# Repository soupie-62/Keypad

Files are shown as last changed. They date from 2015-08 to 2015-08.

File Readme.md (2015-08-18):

Version 2C:
----------
100mm x 60mm<p>
Small enough for cheaper PCB costs<p>
Problems:<p>
	Mounting holes too close too switches<p>

[made pcb]

Version 2B:<p>
----------<p>
49 keys, 120 mm x 55 mm board<p>
Improved button spacing, better mounting hole placement<p>
Problem: Itead Studio want boards <10 cm (100mm)<p>
	Need to move mounting holes, and squeeze buttons together a bit…<p>
<p>
Version 2A:<p>
----------<p>
44 keys, 10cm x 5cm board<p>
Improved button spacing, better mounting hole placement<p>
<p>
<p>
Version 1:<p>
----------<p>
49 keys, 10cm x 5cm board

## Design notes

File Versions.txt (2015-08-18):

Version 2C:
----------
There are now 2 distinct layouts.
#1:	49 Keys, 100mm x 50mm board.
	10 x 5 buttons, with one "double-width" button on bottom row.
	This board, when combined with a large LCD, would be in a typical
	"clamshell" layout, similar to a laptop.

#2:	47 Keys, 100mm x 60mm board.
	2 rows, 4 buttons wide [8 total].
	4 rows, 10 buttons wide, with one "double-width" button on bottom row [39 total].
	This board has a "cutout" area, allowing a smaller LCD to be added to the top.
	"Landscape" layout, similar to a HP 15C

Version #2 is also being developed as an Android app, using the Nexus 7. 

Version 2B:
----------
49 keys, 120 mm x 55 mm board
Improved button spacing, better mounting hole placement

Problem:	Itead Studio want boards <10 cm (100mm)

		Need to move mounting holes, and squeeze buttons together a bit…

Version 2A:
----------
44 keys, 10cm x 5cm board
Improved button spacing, better mounting hole placement

Version 1:
----------
49 keys, 10cm x 5cm board

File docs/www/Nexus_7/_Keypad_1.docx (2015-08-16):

Keypad – some calculations

This keypad needs to be both physical, and virtual (emulated on a tablet). When physical, a “clamshell” design would allow a large keypad, with a large screen that folds over the top when the device is closed.

The emulated version would not be able to do that.

If the keypad and screen form a single unit, dimensions come into play. A screen the same size as the keypad makes the whole device too big. A screen the same width as the keypad, but shorter, might be the right size – but there’s not enough room on the screen.

The next option is: have a narrower (but taller) screen, with keys underneath and to one side. This also allows the screen to show custom labels, for the row of keys immediately below the screen.

The overall height of the screen, and the size of the text, now need to be determined. A failure to fix these risks feature “redesign” slowing overall project progress.

Tablet Dimensions 1: Ipad

The Ipad screen is 1024 x 768. Assuming 100 pixels wide by 96 high, we can fit up to 7 rows on the screen, leaving 96 pixels. By limiting to 4 rows under the “display” section, we get a display height of 384 pixels.

If the display is equal to the width of six keys, that is a total display area of 600 x 384. By using a font width of 30 pixels, 20 characters per line is possible (The old HP 41C supported 16 chars).

For key labels, assuming labels are no more than 6 chars long, the font needs to be about 15 pixels wide (36 chars total). Assuming three rows of key labels, each row 21 pixels high, the label area is 63 pixels.

With a display of 600 x 321 (384 – 63), and a font 42 pixels high, about seven lines of text / numbers can be displayed.

By reducing the height of each key row to 72 pixels, OR reducing to 3 rows of keys, the display increases to 600 x 417 (480 – 63, about 9 lines). Combining these options gives a display of 600 x 489 (552 – 63, 11 lines).

Dot Matrix (extrapolated)

Width | 5 | 10 | 15 | 30 | 50
Height | 7 | 14 | 21 | 42 | 70

Tablet Dimensions 1: Nexus 7 (2013 Edition)

The (2013) Nexus 7 screen is 1920W x 1200H. Assuming buttons are 190W x 160H, we can fit 7 rows on the screen, leaving 80 pixels free. Limit to 4 rows under the “display”, get a display height of (80 + 160 + 160 + 160) 560 pixels.

If the display is six keys wide, the total display area is: 1140W x 560H. Using a font 50 pixels wide, 22 characters per line is possible.

For key labels, assuming labels are no more than 6 chars long, the font needs to be about 30 pixels wide (36 chars total). Assuming three rows of key labels (plain, F and G), each row 40 pixels high, the label area is 120H.

With a display of 1140W x 440H (560 – 120), and a font 70 pixels high, about six lines of text / numbers can be displayed.

The physical dimensions of the Nexus 7 are: 114mm W x 200mm H x 8.65mm D
The screen is: 94mm W x 151 mm D

Each button is 190W. Most buttons have 2 labels above (alpha and green menu) , or 2 labels below (F and G functions). Using a font 20W allows 9 characters per label.

Keycap Size, Spacing and Alignment

Almost all regular PC keyboards use keycaps of the approximate same size. In this context, I am referring to "size" as the width and depth of each keycap (the height of the keycaps we'll examine when we talk about travel (http://www.pcguide.com/ref/kb/const/cap_Travel.htm).) The size of a regular keycap is approximately 0.5 inches (12.7mm) square on the top of the keycap. The keycap then tapers down to a larger size at its base; a little under 0.75 inches (19mm) square (about 11/16ths of an inch).

Spacing of keycaps is also very standardized, at about 0.75 inches from the center of one key to the center of its neighbor on either side. Each row of keys in the main alphanumeric area of the keyboard is also separated by about 0.75 inches of space in a typical keyboard.

The next issue is the alignment of the rows of keys in the main part of the keyboard. By this I mean how the keys in one row are offset, left to right, relative to the keys in the row above and below it. Here too there is a standard configuration which is rarely violated. Let's call the bottom row of alphanumeric keys (containing "Z" and "X") row #1. Then the "home row" containing "A" and "S" would be row #2, the row with "Q" and "W" row #3, and the row with the numeric symbols row #4. Alignment is as follows:

- Row #1 is offset from row #2 by about one-half of a key-spacing. That's 3/8ths (0.375) inches (9.525mm).
- Row #2 is offset from row #3 by about one-quarter of a key-spacing, or 3/16ths (0.188) inches (4.7625mm). This one's the oddball; I don't know why it isn't 3/8ths like the others, but it isn't. :^)
- Row #3 is offset from row #4 by 3/8ths inches like the offset of row #1 and row #2.

Again, we are discussing the regular alphanumeric keys here; the size, spacing and location of the keys other than the main alphanumerics varies greatly from one keyboard to another. These are discussed in the description of keyboard layouts (http://www.pcguide.com/ref/kb/layout/index.htm). Also, special keys such as the <Enter> key and <Space Bar> are often of different sizes and spacing can be very different between models.

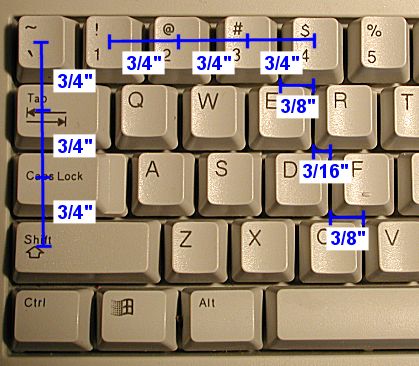
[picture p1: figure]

Illustration of a typical keyboard showing the spacing between
keys and rows of keys, as well as the offsets between adjacent
rows of keys in the main typing area of the keyboard.

The reason for standardized keycap size, spacing and alignment is a simple one: not having a standard would make everyone who has to use more than one keyboard utterly miserable. Touch typists and data entry people learn the "feel" of a keyboard and become used to its spacing and the size of its keys. Moving between two keyboards with different-sized keys or keys with different spacings would slow people down. It would also cause major retraining problems for new employees, or if you bought a new PC, and so on.

There is one place where non-standard keycap size and spacing may sometimes be seen: in very small notebook PCs or PC-like devices. This would be due to the need to conserve space. Fortunately, most notebooks do come with keycaps of standard size and spacing, especially now that if anything, notebooks are getting wider due to the desire for larger screens. However, there is also a growing market for very small "sub-notebooks", and here, "shrunken" keycaps are sometimes found. The exact layout of keys is sometimes a bit strange with notebooks (http://www.pcguide.com/ref/kb/layout/non_Note.htm) but at least usually the regular keys are where they should be--without that, anyone working on both a desktop and notebook machine would find life a bit difficult in this regard.

Keycap Travel

A very important ergonomic and comfort design factor for keyboards is keycap travel. This refers to the distance the keycaps move when the keys are pressed. A keyboard whose keys move down a great deal (relatively speaking) is said to have a "long" travel, while one whose keys move relatively little has a "short" travel. Travel is determined in part by overall keyboard design, but is also a function of the keyswitch technology (http://www.pcguide.com/ref/kb/const/switch.htm) used.

Travel is an important consideration for touch typists and others who use their keyboards a great deal. Good keyboards, all else being equal, usually have a fairly long travel, about 0.15 inches or more. Less expensive keyboards, or keyboards used in applications where saving space is important, often have travel of less than 0.10 inches (2.54mm). The difference may seem insignificant, but it definitely is not. My regular PC keyboard has a travel of about 0.16 inches (4.06mm); my notebook keyboard is about 0.12 inches (3.05mm). I can use both, but the full-sized keyboard is much more comfortable on my fingers.

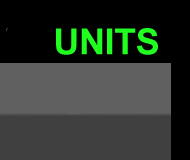
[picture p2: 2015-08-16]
docs/www/Nexus_7/H/H_R2C9.png

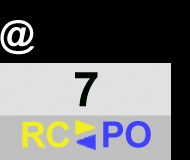
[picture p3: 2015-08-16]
docs/www/Nexus_7/alpha/A_R2C1.png

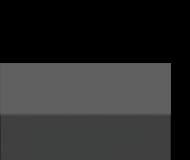
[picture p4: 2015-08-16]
docs/www/Nexus_7/H/H_R1C0.png

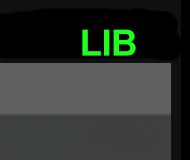
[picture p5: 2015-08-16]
docs/www/Nexus_7/H/H_R4C6.png

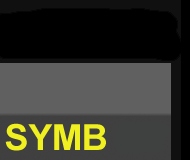
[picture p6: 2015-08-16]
docs/www/Nexus_7/F/F_R5C5.png

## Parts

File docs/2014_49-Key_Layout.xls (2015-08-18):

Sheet: Pad
A | Solve | B | Lib | C | Fin | D | Prob | E | Plot | F | Symb | G |  | I / O | ( | |x| |  | ) | Stk | CLΣ
F1 |  | F2 |  | F3 |  | F4 |  | F5 |  | F6 |  | 1/x |  |  | √x |  |  | ▲ |  | CLR
 |  |  |  |  |  |  |  |  |  |  |  | y^x |  |  | x^2 |  |  | Drop |  | Del
H | Stat | I | Time | J | Units | K | Logic | L | Flags | M | Const | ≈ |  | Mode | < | << |  | # | R↑ | > | >>
× |  | 7 |  | 8 |  | 9 |  | +/- |  | Log |  | Ln |  |  | ◄ |  |  | ▼ |  | ►
ST× |  | RC PO |  | i Ð |  | Δ% |  | X.Fcn |  | 10^x |  | e^x |  |  | [ ] |  |  | R↓ |  | Swap
N |  | O |  | P |  | Q |  | R |  | S | 2d | " |  | π | $ | ∂ |  | ; | ∫ | @ | Σ
÷ |  | 4 |  | 5 |  | 6 |  | EXP |  | x⇄y |  | Hyp |  |  | SIN |  |  | COS |  | TAN
ST÷ :: |  | b/c .d |  | P Cy,x |  | DRG◄ |  | Lin Rg |  | x⇄ |  | " " |  |  | asin |  |  | acos |  | atan
T |  | U |  | V |  | W |  | X |  | Y | 2^x | ! |  | !( ) | & | && |  | | | || | ^ | ^^
+ |  | 1 |  | 2 |  | 3 |  | SST |  | STO |  | RCL |  |  |  |  |  | GTO |  | XEQ
ST+ Σ+ |  | Eval |  | Mod |  | Cat |  | BST |  | ~ not |  | x! |  |  | & and |  |  | | or |  | ^ xor
Z |  | % |  | Space |  |  | RTN | Eqn |  | Eqn Lib |  |  | Prgm |  |  |  | H |  |  |  | Off
- |  | 0 |  | . |  | R / S |  | ENTER |  |  |  | α |  |  | F |  |  | G |  | ON
ST- Σ- |  | H.ms |  | , = |  | LBL |  | Matrix |  |  |  | User |  |  |  |  |  |  |  | Off

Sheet: Thoughts
A |  | Solve |  |  | B |  | Plot |  | C | Symb | D |  | Time | E | Stat | F | Units | G |  | H |  |  |  | ≈ | Stk |  | CLΣ
 |  |  |  |  |  |  |  |  |  |  |  |  |  |  |  |  |  | 1/x |  | √x |  |  |  | ▲ |  |  | CLR
 |  |  |  |  |  |  |  |  |  |  |  |  |  |  |  |  |  | y^x |  | x^2 |x| |  |  |  | Drop |  |  | Del
I |  | Prob |  |  | J |  | Lib |  | K | Eq Lb | L |  | Fin | M | I / O | N | Flags | O |  | < | << |  |  | # |  |  | > | >>
× |  |  |  |  | 7 |  |  |  | 8 |  | 9 |  |  | +/- |  | LOG |  | Ln |  | ◄ |  |  |  | ▼ |  |  | ►
i Ð |  |  |  |  | RC PO |  |  |  | H.ms |  | Δ% |  |  | X.Fcn |  | 10^x |  | e^ 2^x |  | [ ] |  |  |  | R↓ ↑ |  |  | Swap
P |  | Logic |  |  | Q |  | Const |  | R |  | S |  |  | T |  | U |  | V |  | " |  |  |  | ; |  |  | @
÷ |  |  |  |  | 4 |  |  |  | 5 |  | 6 |  |  | EXP |  | x⇄y |  | Hyp |  | SIN |  |  |  | COS |  |  | TAN
Fix :: |  |  |  |  | b/c .d |  |  |  | P Cy,x |  | DRG◄ |  |  | Lin R |  | " " 2d |  | Eqn π |  | asin ∂ |  |  |  | acos ∫ |  |  | atan Σ
W |  |  |  |  | X |  |  |  | Y |  | Z |  |  |  |  | ! |  | & |  | % |  |  |  | ^ |  |  | $ | Cat
+ |  |  |  |  | 1 |  |  |  | 2 |  | 3 |  |  | E N T E R |  | STO |  | RCL |  | Mode |  |  |  | Menu |  |  | XEQ
Sci Σ+ |  |  |  |  |  |  |  |  |  |  |  |  |  |  |  | x! !( ) |  | Eval && |  | Mod || |  |  |  | xor |  |  | GTO
( |  |  |  |  | ) |  |  |  | Space |  |  |  | RTN |  |  | : |  |  | Prgm |  |  | H |  |  |  |  |  | Off
- |  |  |  |  | 0 |  |  |  | . |  | R / S |  |  |  |  | SST |  | α |  | G |  |  |  | F |  |  | ON
Eng Σ- |  |  |  |  |  |  |  |  | , = |  | LBL |  |  | Matrix |  | BST |  | User |  |  |  |  |  |  |  |  | Off
 | Mode: |  |  | 12h |  | 12 Hour Clock |  |  |  |  |  | 10 x 5 = 50 keys (ENTER = 2 spaces) -> 49 Keys |  |  |  |  |  |  |  | ARM Flags: |  | Z | Zero |  |  | C | Carry
 |  |  |  | 1C |  | Integer, 1's Complement |  |  |  |  |  |  |  |  |  |  |  |  |  |  |  | N | Negative |  |  | V | Overflow
 |  |  |  | 24h |  | 24 Hour Clock
 |  |  |  | 2C |  | Integer, 2's Complement
 |  |  |  | Base n |  | Integer, Base (2 to 16)
 |  |  |  | BestF |  | "Best Fit" curve model
 |  |  |  | CAS |  | Computer Algebra System (Symbolic math)
 |  |  |  | CPX |  | Complex math
 |  |  |  | DBL |  | "Double" Precision
 |  |  |  | FAST |  | Faster CPU, uses more battery power (Default)
 |  |  |  | SLOW |  | Slower CPU, saves battery
 |  |  | ANGLE: |  |  |  |  | Symbol font, code 208

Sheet: Pad_1
A |  |  |  | B |  |  | C | D |  |  | E |  | F | G |  |  | H |  |  |  | ^ | Stk |  |  | CLΣ
 |  |  |  |  |  |  |  |  |  |  |  |  |  | 1/x |  |  | √x |  |  |  | ▲ |  |  |  | CLR
Solve |  |  |  | Plot |  |  | Symb | Time |  |  | Stat |  | Units | y^x |  |  | x^2 |x| |  |  |  | Drop |  |  |  | Del
I |  |  |  | J |  |  | K | L |  |  | M | Rem | N | O |  |  | < |  |  |  | & |  |  |  | > |  | Cat
× |  |  |  | 7 |  |  | 8 | 9 |  |  | +/- |  | LOG | Ln |  |  | ◄ |  |  |  | ▼ |  |  |  | ►
i Ð |  |  |  | RC PO |  |  | H.ms | Δ% |  |  | Mod |  | 10^x | e^ 2^x |  |  | [ ] I/O |  |  |  | R↓ ↑ |  |  |  | Swap
P |  |  |  | Q |  |  | R | S |  |  | T | L.R | U | V |  |  | " |  |  |  | ; |  |  |  | @
÷ |  |  |  | 4 |  |  | 5 | 6 |  |  | EXP |  | x⇄y | Hyp |  |  | SIN |  |  |  | COS |  |  |  | TAN
Fix :: |  |  |  | b/c .d |  |  | P Cy,x | DRG◄ |  |  | Print |  | " " 2d | Eqn π |  |  | asin ∂ |  |  |  | acos ∫ |  |  |  | atan Σ
W |  |  |  | X |  |  | Y | Z |  |  |  |  | # | ! |  |  | % |  |  |  | ≈ |  |  |  | $
+ |  |  |  | 1 |  |  | 2 | 3 |  |  | E N T E R |  | STO | RCL |  |  | Mode |  |  |  | Menu |  |  |  | XEQ
Sci Σ+ |  |  |  | Prob |  |  | Lib | Eq Lib |  |  |  |  | Eval | { } x! |  |  | X.Fcn |  |  |  | Flags |  |  |  | GTO
( |  |  |  | ) |  |  | Space |  |  | RTN |  |  | : |  | Prgm |  |  |  |  |  |  |  |  |  |  |  | Off
- |  |  |  | 0 |  |  | . | R / S |  |  |  |  | SST | α |  |  | G |  |  |  | F |  |  |  | ON
Eng Σ- |  |  |  | Fin |  |  | , = | LBL |  |  | Matrix |  | BST | User |  |  |  |  |  |  |  |  |  |  | Off
 | Mode: |  | 12h |  | 12 Hour Clock |  |  |  | 10 x 5 = 50 keys (ENTER = 2 spaces) -> 49 Keys |  |  |  |  |  |  |  | ARM Flags: |  | Z | Zero |  |  |  | C | Carry
 |  |  | 1C |  | Integer, 1's Complement |  |  |  |  |  |  |  |  |  |  |  |  |  | N | Negative |  |  |  | V | Overflow
 |  |  | 24h |  | 24 Hour Clock
 |  |  | 2C |  | Integer, 2's Complement |  |  |  |  |  |  |  |  |  |  | ARM Tests:
 |  |  | Base n |  | Integer, Base (2 to 16) |  |  |  |  |  |  |  |  |  |  | EQ |  | Equal, Z = 1 |  |  |  |  | NE |  | Not Equal, Z = 0
 |  |  | BestF |  | "Best Fit" curve model |  |  |  |  |  |  |  |  |  |  | CS |  | Carry Set, C = 1 |  |  |  |  | CC |  | Carry Clear, C = 0
 |  |  | CAS |  | Computer Algebra System (Symbolic math) |  |  |  |  |  |  |  |  |  |  | HS |  | U / S Higher or Same, C = 1 |  |  |  |  | LO |  | U / S Lower, C = 0
 |  |  | CPX |  | Complex math |  |  |  |  |  |  |  |  |  |  | MI |  | Minus, N = 1 |  |  |  |  | PL |  | Plus, N = 0
 |  |  | DBL |  | "Double" Precision |  |  |  |  |  |  |  |  |  |  | VS |  | Overflow, V = 1 |  |  |  |  | VC |  | No Overflow, V = 0
 |  |  | FAST |  | Faster CPU, uses more battery power (Default) |  |  |  |  |  |  |  |  |  |  | HI |  | U / S Higher, C = 1 , Z = 0 |  |  |  |  | LS |  | U / S Lower or same,
 |  |  | SLOW |  | Slower CPU, saves battery |  |  |  |  |  |  |  |  |  |  |  |  |  |  |  |  |  |  |  |  | C = 0, Z = 1
 |  | ANGLE: |  |  |  | Symbol font, code 208

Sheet: Pad_2
A | B | C | D |  | E |  | F | G |  | H | ^ | Stk | CLΣ
 |  |  |  |  |  |  |  | 1/x |  | √x | ▲ |  | CLR
Solve | Plot | Symb | Time |  | Stat |  | Units | y^x |  | x^2 |x| | Drop |  | Del
I | J | K | L |  | M | Rem | N | O |  | < | & |  | > | Cat
× | 7 | 8 | 9 |  | +/- |  | LOG | Ln |  | ◄ | ▼ |  | ►
i Ð | RC PO | H.ms | Δ% |  | Mod |  | 10^x | e^ 2^x |  | [ ] I/O | R↓ ↑ |  | Swap
P | Q | R | S |  | T | L.R | U | V |  | " | ; |  | @
÷ | 4 | 5 | 6 |  | EXP |  | x⇄y | Hyp |  | SIN | COS |  | TAN
Fix :: | b/c .d | P Cy,x | DRG◄ |  | Print |  | " " 2d | Eqn π |  | asin ∂ | acos ∫ |  | atan Σ
W | X | Y | Z |  |  |  | # | ! |  | % | ≈ |  | $
+ | 1 | 2 | 3 |  | E N T E R |  | STO | RCL |  | Mode | Menu |  | XEQ
Sci Σ+ | Prob | Lib | Eq Lib |  |  |  | Eval | { } x! |  | X.Fcn | Flags |  | GTO
( | ) | Space |  | RTN |  |  | : |  | Prgm |  |  |  |  | Off
- | 0 | . | R / S |  |  |  | SST | α |  | G | F |  | ON
Eng Σ- | Fin | , = | LBL |  | Matrix |  | BST | User |  |  |  |  | Off

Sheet: Menus
Menu |  | Straight | F | H | Menu |  | Straight | F | H | Menu |  | Straight | F | H | Menu |  | Straight |  | F
SOLVE | A |  |  |  | Plot | A | Zoom |  |  | Symb | A |  |  |  | Test | A | == | Equal, Z = 1 | != | Not Equal, Z = 0
 | B |  |  |  |  | B | (x,y) |  |  |  | B |  |  |  |  | B | CS | Carry Set, C = 1 | CC | Carry Clear, C = 0
 | C |  |  |  |  | C | Trace |  |  |  | C |  |  |  |  | C | >= | U / S Higher or Same, C = 1 | < | U / S Lower, C = 0
 | D |  |  |  |  | D | FCN |  |  |  | D |  |  |  |  | D | < 0 | Minus, N = 1 | > 0 | Plus, N = 0
 | E |  |  |  |  | E | Edit |  |  |  | E |  |  |  |  | E | VS | Overflow, V = 1 | VC | No Overflow, V = 0
 | F |  |  |  |  | F | Cancl |  |  |  | F |  |  |  |  | F | > | U / S Higher, C = 1 , Z = 0 | <= | U / S Lower or same, C = 0, Z = 1
Time | A | H.ms | H.d |  | Stat | A |  |  |  | Units | A | Length | Heat
 | B | H.ms+ | H.ms- |  |  | B | x hat |  |  |  | B | Mass | Time
 | C | 12h | 24h |  |  | C | y |  |  |  | C | Volume | Electr
 | D | Ticks |  |  |  | D | r |  |  |  | D | Area | Speed
 | E |  |  |  |  | E | s |  |  |  | E | Freq
 | F |  |  |  |  | F |  |  |  |  | F | Metric | Imperial
Prob | A | Pois |  |  | Lib | A |  |  |  | Eqn Lib | A
 | B | Binom |  |  |  | B |  |  |  |  | B
 | C |  |  |  |  | C |  |  |  |  | C
 | D |  |  |  |  | D |  |  |  |  | D
 | E |  |  |  |  | E |  |  |  |  | E
 | F | P y,x | C y, x |  |  | F |  |  |  |  | F
Mode | A | Int | Real | Double | Menu | A |  |  |  | Flags | A | SF | FS? | VS
 | B | Complex |  | BCD |  | B |  |  |  |  | B | CF | FC? | VC
 | C | DRG► | ◄DRG |  |  | C |  |  |  |  | C | FS?C | FS?S | FS?T
 | D | B2 | B8 | Bn |  | D |  |  |  |  | D | FC?C | FC?S | FC?T
 | E | B10 | B16 |  |  | E |  |  |  |  | E | ISG | ISE
 | F | 1's Comp | 2's Comp |  |  | F |  |  |  |  | F | DSL | DSE | DSZ
Const | A |  |  |  | Logic | A | And | Nand | Xor | TRIG | A | sinh | asinh | D-R
 | B |  |  |  |  | B | Or | Nor | Xnor |  | B | cosh | acosh | D-G
 | C |  |  |  |  | C | Not | TEST | CS |  | C | tanh | atanh | R-D
 | D |  |  |  |  | D | == | != | CC |  | D | sin | asin | R-G
 | E |  |  |  |  | E | <= | < | < 0 |  | E | cos | acos | G-D
 | F |  |  |  |  | F | >= | > | > 0 |  | F | tan | atan | G-R
X.Fcn | A |  |  |  | I/O | A | Save | Load |  | Prgm | A
 | B |  |  |  |  | B | Print |  |  |  | B
 | C |  |  |  |  | C |  |  |  |  | C
 | D |  |  |  |  | D |  |  |  |  | D
 | E |  |  |  |  | E |  |  |  |  | E
 | F |  |  |  |  | F |  |  |  |  | F
Matrix | A | Edit
 | B | Vec
 | C | <-Wid
 | D | Wid->
 | E | Go->
 | F | Go▼

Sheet: DRC
Itead Studio | Inch | mm
Min track: | 0.00591 | 0.15 | recommend >8 mil | Convert: | Inch | mm
Min Clearance | 0.00591 | 0.15 | recommend >8 mil |  | 1 | 25.4
 |  |  |  |  | 0.1 | 2.54
Plated Via Hole | 0.01181 | 0.3 |  |  | 0.01 | 0.254
Plated Via diam | 0.01181 | 0.3
Plated Hole Tol | 0.00315 | 0.08 | tolerance |  | 0.0394 | 1
Unplated Hole Tol | 0.00197 | 0.05 | tolerance |  | 0.3937 | 10
Annular Ring | 0.00591 | 0.15 | 0.5* (Pad Diam - Hole Diam)
Min via pad: | 0.02362 | 0.6
Better: | 0.03 | 0.762 | 12 mil hole, 9 mil annular ring
Used: | 0.035 | 0.889 | 13 mil hole, 11 mil annular ring
 | 0.04 | 1.016 | 14 mil hole, 13 mil annular ring
Copper to edge | 0.01968503937 | 0.5
Silkscreen min | 0.006 | 0.1524
Hole Space | 0.009842519685 | 0.25
Hole to Edge | 0.0157480315 | 0.4
Elecrow
Min track: | 0.006 | 0.1524 | recommend >8 mil
track space | 0.006 | 0.1524 | recommend >8 mil
Pad space | 0.008 | 0.2032
Drill hole | 0.01181102362 | 0.3
Via | 0.02381102362 | 0.6048
OSH Park (4 layer)
Min track: | 0.005 | 0.127
track space | 0.005 | 0.127
Pad space | 0.008 | 0.2032
Drill hole | 0.001 | 0.0254
Annular Ring | 0.004 | 0.1016

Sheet: Diode
Part # | X | Y | Z | C | G | Case | Qty 50: |  | Height |  |  |  |  | Part:W | Part:L
 |  |  |  |  |  |  |  |  |  |  | C
1N1418W -7-F | 0.95 | 0.9 | 4.05 | 3.15 | 2.25 | SOD123 | $8.44 | Digikey | 0.65 |  |  |  | X
 |  |  |  |  |  |  |  |  | 0.55
1N1418WS -7-F | 0.65 | 1.35 | 3.75 | 2.4 | 1.05 | SOD323 | $8.94 | Digikey | 1.5 |  |  | G
 |  |  |  |  |  |  |  |  | 4.3 | Y
 |  |  |  |  |  |  |  |  | 3.1 | Z

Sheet: Switch
Part # | # Pins | PCB: Area | PCB: W | PCB: H | Height | Cost [50] |  | Store | Manuf | Travel | Comments
SKRK | 2 |  |  |  |  |  |  |  | ALPS
SKSFABE010 | 4 | 7.2 | 3.2 | 2.25 | 0.65 | $0.726 | $36.30 | Mouser | ALPS | 0.1
EVQ-PQHB55 | 4 | 23.28 | 4.85 | 4.8 | 0.55 | $0.391 | $19.53 | Digi-Key | Panasonic
TL-3313 A-F100-Q-G | 4 | 25.6 | 6.4 | 4 | 1.5 |  |  |  | E-Switch
TL-3301 N-F160-Q-J | 4 | 41.3 | 7 | 5.9 | 4.3 | $0.522 | $26.11 | Digi-Key | E-Switch |  | J-Lead: folds under body
B3FS | 4 | 56.64 | 9.6 | 5.9 | 3.1 |  |  |  | Omron
EVP-AA 002K | 4 | 11.25 | 4.5 | 2.5 |  | $0.954 | $47.68 | Digi-Key | Panasonic
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

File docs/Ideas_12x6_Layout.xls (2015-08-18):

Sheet: Sheet1
A6 |  | A7 |  | A8 |  |  | A3 | A4 | A5 | A
A0 |  | A1 |  | A2 |  |  | B3 | B4 | B5 | B
B0 |  | B1 |  | B2 |  |  | B8 | B7 | B6
C0 |  | C1 |  | C2 |  |  | C8 | C7 | C6
D6 |  | D7 |  | D8 |  |  | C3 | C4 | C5 | C
D0 |  | D1 |  | D2 |  |  | D3 | D4 | D5 | D
0 |  | 1 |  | 2 |  |  | 3 | 4 | 5
 | 6 |  | 7 |  | 8
 |  |  |  |  |  | 9 x 4 = 36 Keys

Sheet: Sheet2
A | A1 |  | A2 |  |  | A3 |  | A4 |  | A5 | A6 | A7
 | A0 |  | B2 |  |  | B3 |  | B4 |  | B5 | B6 | A8
B | B0 |  | B1 |  |  | C3 |  | C4 |  | C6 | B7 | B8
C | C0 |  | C1 |  |  | D3 |  | C5 |  | C7
D | D0 |  | C2 |  |  | D4 |  | D6 |  | C8
 | D1 |  | D2 |  |  | D5 |  | D7 |  | D8
 | 1 |  |  | 3 | 4 |  | 6 |  |  | 8
 |  | 0 | 2 |  |  | 5 |  | 7
 |  |  |  |  |  |  |  |  | 9 x 4 = 36 Keys

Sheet: 6x6
 |  |  |  | 2-0-0 | 2 boards | 0 offset | 0 width offset
 |  |  |  | 9cm W x 6cm H |  | each
 |  |  |  | Total width: 9 + 9 |  |  | 18 | cm
 |  |  |  | Key Width: | 1.5 | w
 |  |  |  |  |  | Breaks Spacebar (X)
X | X
 |  |  |  | 2-1-1 |  | 1 offset | 1 width offset
 |  |  |  | Total width: 9 + (9 x 5/7) |  |  | 15.43 | cm
 |  |  |  | Folded: | 12.857 | W | 9 | H
 |  |  |  | Key Width: | 1.286 | w
X | X
 |  |  |  |  |  |  |  |  |  |  | X | X
 |  |  |  | 2-1-2 |  | 1 offset | 2 width offset
 |  |  |  | Total width: 9 + (9 x 4/8) |  |  | 13.50 | cm
 |  |  |  | Folded: | 9 | W | 9 | H
X | X |  |  | Key Width: | 1.125 | w
 |  |  |  |  |  |  |  |  | X | X
 |  |  |  | 2-2-1 |  | 2 offsets | 1 width offset
 |  |  |  | Total width: 9 + (9 x 5/7) |  |  | 15.43 | cm
X | X |  |  | Key Width: | 1.286 | w
 |  |  |  |  |  |  |  |  |  |  |  | X | X
 |  |  |  | 2-2-2 |  | 2 offsets | 2 width offset
 |  |  |  | Total width: 9 + (9 x 4/8) |  |  | 13.50 | cm
 |  |  |  | Folded: | 11.25 | W
X | X |  |  | Key Width: | 1.125 | w
 |  |  |  |  |  |  |  |  |  |  | X | X
 |  |  |  | 2-2-3 |  | 2 offsets | 3 width offset
 |  |  |  | Total width: 9 + (9 x 3/9) |  |  | 12.00 | cm
 |  |  |  | Folded: | 9 | W
X | X |  |  | Key Width: | 1 | w
 |  |  |  |  |  |  |  |  |  | X | X
 |  |  |  | 8 x 5:
 |  |  |  | 2-0-0 |  | 10cm W x 6cm H |  | each
 |  |  |  | 2 boards | 0 offset | 0 width offset
 |  |  |  | Breaks Spacebar (X)
 |  |  |  | Total width: 10 + 10 |  |  | 20 | cm
 |  | X | X | Key Width: | 1.250 | w
 |  |  |  | 2-5-1 | 5 offset | 1 width offset
 |  |  |  | Spacebar preserved (X)
 |  |  |  | Total width: 10 + (10 x 6/10) |  |  | 16.00 | cm
 |  |  |  | Folded: | 15.000 | W | 7.2 | H
 |  | X | X | Key Width: | 1.000 | w |  |  |  |  |  |  |  | X | X
 |  |  |  | 2-5-1 | 5 offset | 2 width offset
 |  |  |  | Total width: 10 + (10 x 4/12) |  | 13.33 | cm
 |  |  |  | Folded: | 11.667 | W | 9 | H
 |  | X | X | Key Width: | 0.833 | w |  |  |  |  |  |  | X | X

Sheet: 8x5
 |  | 2-0-0 |  | 10cm W x 6cm H |  | each
 |  | 2 boards | 0 offset | 0 width offset
 |  | Breaks Spacebar (X)
 |  | Total width: 10 + 10 |  |  | 20 | cm
X | X | Key Width: | 1.250 | w
 |  | 2-5-1 | 5 offset | 1 width offset
 |  | Spacebar preserved (X)
 |  | Total width: 10 + (10 x 6/10) |  |  | 16.00 | cm
 |  | Folded: | 15.000 | W | 7.2 | H
X | X | Key Width: | 1.000 | w |  |  |  | X | X
 |  | 2-5-1 | 5 offset | 2 width offset
 |  | Total width: 10 + (10 x 4/12) |  | 13.33 | cm
 |  | Folded: | 11.667 | W | 9 | H
X | X | Key Width: | 0.833 | w |  |  | X | X

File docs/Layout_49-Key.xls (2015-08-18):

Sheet: HP1
5.1" = 129.54mm W
3.1" = 78.74mm H

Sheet: Pad_1
A |  | Solve |  | B |  | Plot | C | Symb | D |  | Time | E | Stat | F | Units | G |  |  | H |  |  |  | ≈ | Stk |  |  | CLΣ
 |  |  |  |  |  |  |  |  |  |  |  |  |  |  |  | 1/x |  |  | √x |  |  |  | ▲ |  |  |  | CLR
 |  |  |  |  |  |  |  |  |  |  |  |  |  |  |  | y^x |  |  | x^2 |x| |  |  |  | Drop |  |  |  | Del
I |  | Prob |  | J |  | Lib | K | Eq Lb | L |  | Fin | M | I / O | N | Flags | O |  |  | < |  | << |  | # |  |  |  | > |  | >>
× |  |  |  | 7 |  |  | 8 |  | 9 |  |  | +/- |  | LOG |  | Ln |  |  | ◄ |  |  |  | ▼ |  |  |  | ►
i Ð |  |  |  | RC PO |  |  | H.ms |  | Δ% |  |  | X.Fcn |  | 10^x |  | e^ 2^x |  |  | [ ] |  |  |  | R↓ ↑ |  |  |  | Swap
P |  | Logic |  | Q |  | Const | R |  | S |  |  | T |  | U |  | V |  |  | " |  |  |  | ; |  |  |  | @
÷ |  |  |  | 4 |  |  | 5 |  | 6 |  |  | EXP |  | x⇄y |  | Hyp |  |  | SIN |  |  |  | COS |  |  |  | TAN
Fix :: |  |  |  | b/c .d |  |  | P Cy,x |  | DRG◄ |  |  | Lin R |  | " " 2d |  | Eqn π |  |  | asin ∂ |  |  |  | acos ∫ |  |  |  | atan Σ
W |  |  |  | X |  |  | Y |  | Z |  |  |  |  | ! |  | & |  |  | % |  |  |  | ^ |  |  |  | $ |  | Cat
+ |  |  |  | 1 |  |  | 2 |  | 3 |  |  | E N T E R |  | STO |  | RCL |  |  | Mode |  |  |  | Menu |  |  |  | XEQ
Sci Σ+ |  |  |  |  |  |  |  |  |  |  |  |  |  | x! !( ) |  | Eval && |  |  | Mod || |  |  |  | xor |  |  |  | GTO
( |  |  |  | ) |  |  | Space |  |  |  | RTN |  |  | : |  |  | Prgm |  |  |  |  | H |  |  |  |  |  |  | Off
- |  |  |  | 0 |  |  | . |  | R / S |  |  |  |  | SST |  | α |  |  | G |  |  |  | F |  |  |  | ON
Eng Σ- |  |  |  |  |  |  | , = |  | LBL |  |  | Matrix |  | BST |  | User |  |  |  |  |  |  |  |  |  |  | Off
 | Mode: |  | 12h |  | 12 Hour Clock |  |  |  |  | 10 x 5 = 50 keys (ENTER = 2 spaces) -> 49 Keys |  |  |  |  |  |  |  |  | ARM Flags: |  |  | Z | Zero |  |  | C |  | Carry
 |  |  | 1C |  | Integer, 1's Complement |  |  |  |  |  |  |  |  |  |  |  |  |  |  |  |  | N | Negative |  |  | V |  | Overflow
 |  |  | 24h |  | 24 Hour Clock
 |  |  | 2C |  | Integer, 2's Complement
 |  |  | Base n |  | Integer, Base (2 to 16) |  |  |  |  |  |  |  |  |  |  |  |  | EQ |  | Equal, Z = 1 |  |  |  |  | NE |  |  | Not Equal, Z = 0
 |  |  | BestF |  | "Best Fit" curve model |  |  |  |  |  |  |  |  |  |  |  |  | CS |  | Carry Set, C = 1 |  |  |  |  | CC |  |  | Carry Clear, C = 0
 |  |  | CAS |  | Computer Algebra System (Symbolic math) |  |  |  |  |  |  |  |  |  |  |  |  | HS |  | U / S Higher or Same, C = 1 |  |  |  |  | LO |  |  | U / S Lower, C = 0
 |  |  | CPX |  | Complex math |  |  |  |  |  |  |  |  |  |  |  |  | MI |  | Minus, N = 1 |  |  |  |  | PL |  |  | Plus, N = 0
 |  |  | DBL |  | "Double" Precision |  |  |  |  |  |  |  |  |  |  |  |  | VS |  | Overflow, V = 1 |  |  |  |  | VC |  |  | No Overflow, V = 0
 |  |  | FAST |  | Faster CPU, uses more battery power (Default) |  |  |  |  |  |  |  |  |  |  |  |  | HI |  | U / S Higher, C = 1 , Z = 0 |  |  |  |  | LS |  |  | U / S Lower or same, C = 0, Z = 1
 |  |  | SLOW |  | Slower CPU, saves battery

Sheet: Funcs
Row | Col | Key | F | G | Alpha | Row | Col | Key | F | G | Alpha
1 | 1 | USR-1 | Solve | G-USR1 | A | 3 | 6 | X><Y | " " | 2d | U
1 | 2 | USR-2 | Plot | G-USR2 | B | 3 | 7 | Hyp | Eqn | p | V
1 | 3 | USR-3 | Symb | G-USR3 | C | 3 | 8 | SIN | asin | ∂ | "
1 | 4 | USR-4 | Time | G-USR4 | D | 3 | 9 | COS | acos | ∫ | ;
1 | 5 | USR-5 | Stat | G-USR5 | E | 3 | 10 | TAN | atan | Σ | @
1 | 6 | USR-6 | Units | G-USR6 | F | 4 | 1 | + | Sci | Σ+ | W
1 | 7 | 1/X | Y^x |  | G | 4 | 2 | 1 | Prob | ISG | X
1 | 8 | SQRT | x^2 | |x| | H | 4 | 3 | 2 | Lib |  | Y
1 | 9 | ▲ | Drop | Stack | ^ | 4 | 4 | 3 | Eqn Lib |  | Z
1 | 10 | CLR | Del | CL Σ |  | 4 | 5 | ENTER | Matrix | Const
2 | 1 | X | i | Ð | I | 4 | 6 | STO | Eval |  | #
2 | 2 | 7 | Rect | Polar | J | 4 | 7 | RCL | { } | x! | !
2 | 3 | 8 | H.d | H.ms | K | 4 | 8 | Mode | X.FCN |  | %
2 | 4 | 9 | % | D% | L | 4 | 9 | Menu | Flags |  | ≈
2 | 5 | +/- | Mod | Rem | M | 4 | 10 | XEQ | GTO |  | $
2 | 6 | LOG | 10^x |  | N | 5 | 1 | - | Eng | Σ- | (
2 | 7 | LN | e^x | 2^x | O | 5 | 2 | 0 | Fin | DSE | )
2 | 8 | ◄ | [ ] | I/O | < | 5 | 3 | . | , | = | Space
2 | 9 | ▼ | RDN | R up | & | 5 | 4 | R/S | LBL | RTN
2 | 10 | ► | Swap | Cat | >
3 | 1 | / | Fix | :: | P | 5 | 6 | SST | BST |  | :
3 | 2 | 4 | A b/c | a.d | Q | 5 | 7 | Alpha | User
3 | 3 | 5 | P y,x | C y,x | R | 5 | 8 | G
3 | 4 | 6 | DRG | DRG◄ | Space | 5 | 9 | F
3 | 5 | EXP | Print | L.R | T | 5 | 10 | ON | Off | Off

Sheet: LCD
(inch) | mm | mm | mm |  |  |  |  | V | V | mW | mW |  |  | mA | mA |  |  |  | (cd/m²)
Size | Module W | Module H | Depth | Pixel W | Pixel H | Resolution | Name | Dig V | An V | LCD | Light | Volts | Notes | Dig I | An I |  | Active W | Active H | Brightness | Contrast | Used in: |  |  | Width /6 | 5x8 chars | 8x12 | 12x16 | 16x16
 | 44 | 34 | 1.6 | 128 | 64 |  | CFAX12864T-NFH |  |  |  |  |  |  |  |  |  |  |  |  |  |  |  |  | 21.33333333 | 4.266666667 | 2.666666667 | 1.777777778 | 1.333333333
 | 94 | 47 | 2.8 | 240 | 128 |  | dogxl240-7e |  |  |  |  |  |  |  |  |  |  |  |  |  |  |  |  | 40 | 8 | 5 | 3.333333333 | 2.5
 |  |  |  |  |  |  |  |  |  |  |  |  |  |  |  |  |  |  |  |  | iPhone 2, early Android |  |  | 0 | 0 | 0 | 0 | 0
3.5" | 85 | 56 | 2.1 | 480 | 320 | HVGA | 35HVF0H_E | 1.8 | 2.8 | 13 | 320 |  |  | 7.22 | 114.29 |  | 75.56 | 51.14 |  |  |  |  |  | 80 | 16 | 10 | 6.666666667 | 5
4.0" | 96 | 57 | 1.8 | 800 | 480 | WVGA | ASIT400NB3MND | 1.8 | 2.8 | 20 mA |  | 25.4V | MIPI |  |  |  | 86.4 | 51.84 |  |  | AKA - WGA |  |  | 133.3333333 | 26.66666667 | 16.66666667 | 11.11111111 | 8.333333333
4.0" | 97 | 58 | 1.85 | 800 | 480 | WVGA | Sharp LQ040Y3DX80 | 1.8 | 2.8 | 20mA |  | 25V | Driver: NT 35512 |  |  |  | 86.4 | 51.84 |  |  |  |  |  | 133.3333333 | 26.66666667 | 16.66666667 | 11.11111111 | 8.333333333
4.3 | 105.9 | 62.46 | 2.1 | 800 | 480 | WVGA | LQ043Y1DX07 |  |  |  |  |  |  |  |  | $138 (Mouser) | 93.6 | 56.16 |  |  | HTC Desire HD |  |  | 133.3333333 | 26.66666667 | 16.66666667 | 11.11111111 | 8.333333333
4.0" | 98.3 | 62.6 | 3.8 | 480 | 272 | 16:09:00 | LTE400WQ-F01 (http://www.encore-electronic.com/samsung/lte400wq-f01/) |  |  |  |  |  | encore-electronic.com | SAMSUNG |  |  | 87.84 | 49.77 | 250 | 300:01:00 |  |  |  | 80 | 16 | 10 | 6.666666667 | 5
4.0" | 98.3 | 62.6 | 3.8 | 480 | 272 | 16:09:00 | A040FL01-V0 (http://www.encore-electronic.com/auo/a040fl01-v0/) |  |  |  |  |  | encore-electronic.com | AUO |  |  | 87.84 | 49.77 | 230 | 300:01:00 |  |  |  | 80 | 16 | 10 | 6.666666667 | 5
4.0" | 98.3 | 62.6 | 3.8 | 480 | 272 | 16:09:00 | A040FL01-V1 (http://www.encore-electronic.com/auo/a040fl01-v1/) |  |  |  |  |  | encore-electronic.com | AUO |  |  | 87.84 | 49.77 | 280 | 280:01:00 |  |  |  | 80 | 16 | 10 | 6.666666667 | 5
4.0" | 98.3 | 62.6 | 3.8 | 480 | 272 | 16:09:00 | A040FL01-V5 (http://www.encore-electronic.com/auo/a040fl01-v5/) |  |  |  |  |  | encore-electronic.com | AUO |  |  | 87.84 | 49.77 | 350 | 500:01:00 |  |  |  | 80 | 16 | 10 | 6.666666667 | 5
4.0" | 98.3 | 62.6 | 3.2 | 480 | 272 | 16:09:00 | HTT40WQ1-M04 (http://www.encore-electronic.com/hydis/htt40wq1-m04/) |  |  |  |  |  | encore-electronic.com | Hydis |  |  | 87.84 | 49.77 | 200 | 450:01:00 |  |  |  | 80 | 16 | 10 | 6.666666667 | 5
4.0" | 98.3 | 62.6 | 2.9 | 480 | 272 | 16:09:00 | LTE400WQ-F04 (http://www.encore-electronic.com/samsung/lte400wq-f04/) |  |  |  |  |  | encore-electronic.com | SAMSUNG |  |  | 87.84 | 49.77 |  | 300:01:00 |  |  |  | 80 | 16 | 10 | 6.666666667 | 5
 | 106 | 63 | 2.1 | 800 | 480 | WVGA | Sharp LQ043Y1DX07 |  |  |  |  | 3.3V |  |  |  |  |  |  |  |  |  |  |  | 133.3333333 | 26.66666667 | 16.66666667 | 11.11111111 | 8.333333333
4.0" | 97.69 | 63.24 | 4.05 | 800 | 480 | 3:05:00 | UF80I010A (http://www.encore-electronic.com/samsung/uf80i010a/) |  |  |  |  |  | Discontinued | SAMSUNG |  |  | 86.4 | 51.84 | 200 | 300:01:00 |  |  |  | 133.3333333 | 26.66666667 | 16.66666667 | 11.11111111 | 8.333333333
4.3 | 105.5 | 67.2 | 3.1 | 480 | 272 | HVGA | HDA430-3H |  |  |  |  |  |  |  |  |  | 95.04 | 53.86 |  |  | 16:9 variant |  |  | 80 | 16 | 10 | 6.666666667 | 5
 | 99 | 68 | 2.9 | 240 | 128 |  | Winstar WO240128A
 | 106 | 68 | 2.95 | 480 | 272 |  | WF43G_TFT
 | 106 | 68 | 3.1 | 480 | 272 |  | HDA430-3h
4.3" | 106 | 68 | 4.2 | 480 | 272 |  | Sharp LQ043T1DG28 (http://www.sharpsma.com/lcds/2-4-inch-5-12-cm/LQ043T1DG28)
 | 120 | 76 | 3 | 800 | 480 | WVGA | OT-COG500-1P |  |  |  |  | 3.3V
 | 119 | 78 | 3.4 | 800 | 480 | WVGA | HSD050IDW1-A |  |  |  |  | 5V
 |  |  |  | 960 | 640 | DVGA |  |  |  |  |  |  |  |  |  |  |  |  |  |  | iPhone 4 "Retina Display" |  |  | 160 | 32 | 20 | 13.33333333 | 10
24 |  |  |  | 1920 | 1200 | WUXGA |  |  |  |  |  |  |  |  |  |  |  |  |  |  | Home PC |  |  | 320 |  | 40 | 26.66666667 | 20
 |  |  |  |  |  |  |  |  |  |  |  |  |  |  |  |  |  |  |  |  | W | H | Pixels | Bytes | x2 Pages
 |  |  |  |  |  |  |  |  |  |  |  |  |  |  |  |  |  |  |  |  | 800 | 480 | 384000 | 1152000 | 2304000
 |  |  |  |  |  |  |  |  |  |  |  |  |  |  |  |  |  |  |  |  | 480 | 320 | 153600 | 460800 | 921600
 |  |  |  |  |  |  |  |  |  |  |  |  |  |  |  |  |  |  |  |  | 480 | 272 | 130560 | 391680 | 783360

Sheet: Dimensions
Model | Length | Width | Height | Display | Battery | CPU | Area | Vol
 | cm | cm | cm |  |  |  | cm^2 | cm^3
 |  |  |  |  |  |  |  | ml
DM-15CC | 5.7 | 8.1 | 0.8 | 132 x 16 pixel | 1x CR2032 (3V 225mAh) | LPC1114 ARM CPU | 46.2 | 36.9
My Keypad | 6 | 10 | 1 |  |  |  | 60.0 | 60.0
HP-15C | 7.9 | 12.9 | 1.5 | 10 digit 7-segment | 2x CR2032 | Atmel AT91SAM7L128 30 MHz processor | 101.9 | 152.9
WP 34S | 15 | 7.7 | 1.7 | Top: 43x6 dot matrix Bottom: 12 digit 7-segment +3 digit exp | 2x CR2032 | Atmel AT91SAM7L128 30 MHz | 115.5 | 196.3
HP Prime | 18.23 | 8.58 | 1.39 | 320 x 240 Colour Touch 10 lines x 33char + menu + header | Lithium rechareable 3.7V 1500mAh | Samsung S3C2416XH-40 - ARM9 (core: ARM926EJ-S), 400 MHz max | 156.4 | 217.4
HP-41C | 14.3 | 7.8 | 3.1 | 12 digit 14-segment | 4x N Cell (1.5V 800mAh ea) | HP "Coconut" | 111.5 | 345.8
HP 50G | 18.4 | 8.7 | 2.3 | 131 x 80 pixel | 3x AAA (1.5V 1200mAh ea) | ARM920T (Samsung S3C2410X), 75 MHz | 160.1 | 368.2
HP-71B | 9.6 | 19.2 | 2.6 | 72 x 8 pixel, 12 x 1 char | 4x AAA |  | 184.3 | 479.2
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

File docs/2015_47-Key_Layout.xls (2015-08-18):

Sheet: Pad
 | A |  |  |  |  |  | B |  |  |  |  |  | C |  |  |  |  | D |  |  |  |  | E |  |  |  |  | F |  |  |  |  | ( |  |  |  | ) |  | |x| |  |  |  | ≈ |  | Stk |  | CLΣ
 | F1 |  |  |  |  |  | F2 |  |  |  |  |  | F3 |  |  |  |  | F4 |  |  |  |  | F5 |  |  |  |  | F6 |  |  |  |  | 1/x |  |  |  | √x |  |  |  |  |  | ▲ |  |  |  | CLR
 |  |  |  |  |  |  |  |  |  |  |  |  |  |  |  |  |  |  |  |  |  |  |  |  |  |  |  |  |  |  |  |  | y^x |  |  |  | x^2 |  |  |  |  |  | Drop |  |  |  | Del
 | G |  | Solve |  |  |  | H |  | Lib |  |  |  | I |  | Fin |  |  | J |  | Prob |  |  | K |  |  |  |  | L |  | 2^x |  |  | : |  |  |  | < |  | << |  |  |  | # |  | R↑ |  | > |  | >>
 | × |  |  |  |  |  | 7 |  |  |  |  |  | 8 |  |  |  |  | 9 |  |  |  |  | +/- |  |  |  |  | Log |  |  |  |  | Ln |  |  |  | ◄ |  |  |  |  |  | ▼ |  |  |  | ►
 | ST× |  |  |  |  |  | RC PO |  |  |  |  |  | i Ð |  |  |  |  | Δ% |  |  |  |  | X.Fcn |  |  |  |  | 10^x |  |  |  |  | e^x |  |  |  | [ ] |  |  |  |  |  | R↓ |  |  |  | Swap
 | M |  | Stat |  |  |  | N |  | Time |  |  |  | O |  | Units |  |  | P |  | Logic |  |  | Q |  |  |  |  | R |  | 2d |  |  | " |  | π |  | $ |  | ∂ |  |  |  | ; |  | ∫ |  | @ |  | Σ
 | ÷ |  |  |  |  |  | 4 |  |  |  |  |  | 5 |  |  |  |  | 6 |  |  |  |  | EXP |  |  |  |  | Hyp |  |  |  |  | SIN |  |  |  | COS |  |  |  |  |  | TAN |  |  |  | x⇄y
 | ST÷ :: |  |  |  |  |  | b/c .d |  |  |  |  |  | P Cy,x |  |  |  |  | DRG◄ |  |  |  |  | Lin Rg |  |  |  |  | " " |  |  |  |  | asin |  |  |  | acos |  |  |  |  |  | atan |  |  |  | x!
 | S |  | Plot |  |  |  | T |  | Symb |  |  |  | U |  | I / O |  |  | V |  | Const |  |  | W |  |  |  |  | X |  | RTN |  |  | ! |  | !( ) |  | & |  | && |  |  |  | | |  | || |  | ^ |  | ^^
 | + |  |  |  |  |  | 1 |  |  |  |  |  | 2 |  |  |  |  | 3 |  |  |  |  | SST |  |  |  |  | XEQ |  |  |  |  |  |  |  |  |  |  |  |  |  |  | STO |  |  |  | RCL
 | ST+ Σ+ |  |  |  |  |  | Eval |  |  |  |  |  | Mod |  |  |  |  | Cat |  |  |  |  | BST |  |  |  |  | GTO |  |  |  |  | ~ not |  |  |  | & and |  |  |  |  |  | | or |  |  |  | ^ xor
 | Y |  | Mode |  |  |  | Z |  | Flags |  |  |  | Space |  |  |  |  | % |  | Eqn |  |  |  |  |  |  |  | Eqn Lib |  |  |  |  |  | LBL |  |  |  |  |  |  | H |  |  |  |  |  |  |  | Off
 | - |  |  |  |  |  | 0 |  |  |  |  |  | . |  |  |  |  | R / S |  |  |  |  | ENTER |  |  |  |  |  |  |  |  |  | α |  |  |  | F |  |  |  |  |  | G |  |  |  | ON
 | ST- Σ- |  |  |  |  |  | H.ms |  |  |  |  |  | , = |  |  |  |  | Prgm |  |  |  |  | Matrix |  |  |  |  |  |  |  |  |  | User |  |  |  |  |  |  |  |  |  |  |  |  |  | Off
 | Original: |  |  |  |  |  |  |  |  |  | 49 |  |  |  | Keys
 |  |  |  |  |  |  |  |  |  |  |  |  |  |  |  |  |  |  |  | ! |  |  | 34-S 41 Keys (original: 37)
 | F |  |  |  |  |  | G |  |  |  |  |  | H |  |  |  |  | ▲
 |  |  |  |  |  |  |  |  |  |  |  |  |  |  |  |  |  | C Py,x
 |  |  |  |  |  |  |  |  |  |  |  |  |  |  |  |  |  |  |  | Status
 |  |  |  |  |  |  |  |  |  |  |  |  |  |  |  |  |  | ▼
 |  |  |  |  |  |  |  |  |  |  |  |  |  |  |  |  |  | SF CF
 |  |  | Rmdr |  |  |  |  |  | AND |  |  |  |  |  | OR |  |  |  |  | XOR
 | ÷ |  |  |  |  |  | 7 |  |  |  |  |  | 8 |  |  |  |  | 9
 | 1/x | | |  |  |  |  |  | 10^x LG |  |  |  |  |  | 2^x LB |  |  |  |  | y^x Logₓ
 |  |  | Matrx |  |  |  |  |  | Prob |  |  |  |  |  | Stat |  |  |  |  | Sums |  |  |  |  | ALL |  |  |  |  | FIX |  |  |  |  | SCI |  |  |  | ENG |  |  |  |  |  |  |  | CLx
 | × |  |  |  |  |  | 4 |  |  |  |  |  | 5 |  |  |  |  | 6 |  |  |  |  | A |  |  |  |  | B |  |  |  |  | C |  |  |  | D |  |  |  |  |  |  |  |  |  | CLR
 | √x x^2 |  |  |  |  |  | Φ -1 |  |  |  |  |  | x̄ s |  |  |  |  | ŷ r |  |  |  |  | HYP-1 |  |  |  |  | SIN-1 |  |  |  |  | COS-1 |  |  |  | TAN-1 |  |  |  |  |  |  |  |  |  | CLP CLΣ
 |  |  | Σ- |  |  |  |  |  | Test |  |  |  |  |  | P.Fcn |  |  |  |  | X.Fcn |  |  |  |  | π |  |  |  |  | NOT |  |  |  |  | GTO |  |  |  | x⇄ |  |  |  |  |  | CONV |  |  |  | R↑
 | — |  |  |  |  |  | 1 |  |  |  |  |  | 2 |  |  |  |  | 3 |  |  |  |  | EXP |  |  |  |  | +/- |  |  |  |  | XEQ |  |  |  | x⇄y |  |  |  |  |  | → |  |  |  | R↓
 | % Δ% |  |  |  |  |  | x= ≠ ? |  |  |  |  |  | SLV ∫ |  |  |  |  | π Σ |  |  |  |  | 10 16 |  |  |  |  | 2 8 |  |  |  |  | α |  |  |  | ◄ ► |  |  |  |  |  | R ⇄ P |  |  |  | Ran Grad
 |  |  | Σ+ |  |  |  |  |  | Pse |  |  |  | Space |  |  |  |  |  |  | P / R |  |  | CONST |  |  |  |  |  |  |  |  |  |  |  | CAT |  |  |  | View |  |  |  |  |  | Mode |  | Off
 | + |  |  |  |  |  | 0 |  |  |  |  |  | . |  |  |  |  | R / S |  |  |  |  | ENTER |  |  |  |  |  |  |  |  |  | STO |  |  |  | RCL |  |  |  |  |  | CPX |  |  |  | EXIT
 | DSE ISG |  |  |  |  |  | |x| Rnd |  |  |  |  |  | , = |  |  |  |  | Lbl Rtn |  |  |  |  | α FILL |  |  |  |  |  |  |  |  |  | H.ms Deg |  |  |  | H.d Rad |  |  |  |  |  | ab/c d/c |  |  |  | Show
 |  |  |  |  |  |  |  |  |  |  |  |  | RTN |  |  |  |  | Undo |  |  |  |  | WP-43 41 Keys (original: 43)
 | F |  |  |  |  |  | G |  |  |  |  |  | ▲ |  |  |  |  | ←
 |  |  |  |  |  |  |  |  |  |  |  |  | I/O |  |  |  |  | Clear
 | A |  | x⇄ |  |  |  | B |  | R↑ |  |  |  | Status |  |  |  |  | C |  | Ð
 | x⇄y |  |  |  |  |  | R↓ |  |  |  |  |  | ▼ |  |  |  |  | i
 | Uconv |  |  |  |  |  | Stack |  |  |  |  |  | Info |  |  |  |  | CPX
 | D |  | Rmdr |  |  |  | E |  |  |  |  |  | F |  |  |  |  | G
 | ÷ |  |  |  |  |  | 7 |  |  |  |  |  | 8 |  |  |  |  | 9
 | Matrix |  |  |  |  |  | Sums |  |  |  |  |  | Stat |  |  |  |  | Prob
 | H |  | x! |  |  |  | I |  |  |  |  |  | J |  |  |  |  | K |  |  |  |  |  |  |  |  |  |  |  |  |  |  |  |  |  |  |  |  |  |  |  |  | L |  | GTO |  | M |  | .dec
 | × |  |  |  |  |  | 4 |  |  |  |  |  | 5 |  |  |  |  | 6 |  |  |  |  |  |  |  |  |  |  |  |  |  |  |  |  |  |  |  |  |  |  |  |  | XEQ |  |  |  | π
 | TVM |  |  |  |  |  | EQN |  |  |  |  |  | Solve |  |  |  |  | POL |  |  |  |  |  |  |  |  |  |  |  |  |  |  |  |  |  |  |  |  |  |  |  |  | Loop |  |  |  | Displ
 | N |  | Δ% |  |  |  | O |  |  |  |  |  | P |  |  |  |  | Q |  |  |  |  | R |  | >Pol |  |  | S |  | >Rec |  |  | T |  | a b/c |  | U |  | base |  |  |  | V |  | h.ms |  | W |  | d.ms
 | — |  |  |  |  |  | 1 |  |  |  |  |  | 2 |  |  |  |  | 3 |  |  |  |  | +/- |  |  |  |  | EEX |  |  |  |  | 1/x |  |  |  | LOGS |  |  |  |  |  | √x |  |  |  | TRIG
 | FIN |  |  |  |  |  | Bits |  |  |  |  |  | Boole |  |  |  |  | X.Fcn |  |  |  |  | Const |  |  |  |  | Geom |  |  |  |  | Fracs |  |  |  | Ints |  |  |  |  |  | Clock |  |  |  | ÐConv
 | ? |  | % + |  |  |  | X |  | Show |  |  |  | Y |  | Disp |  |  | Z |  | Prgm |  |  | Fill |  |  |  |  |  |  |  |  |  | , |  | Save |  | _ |  | Load |  |  |  | α
 | + |  |  |  |  |  | 0 |  |  |  |  |  | . |  |  |  |  | R / S |  |  |  |  | ENTER |  |  |  |  |  |  |  |  |  | STO |  |  |  | RCL |  |  |  |  |  | USER |  |  |  | Exit
 | Tests |  |  |  |  |  | Parts |  |  |  |  |  | Flags |  |  |  |  | P.Fcn |  |  |  |  | Catalog |  |  |  |  |  |  |  |  |  | Assign |  |  |  | View |  |  |  |  |  | MODES |  |  |  | On
 |  |  |  |  | H |  |  |  |  |  |  | ^ |  |  |  |  |  | Undo |  |  |  |  |  |  |  | NC-17 : 47 Keys
 | F |  |  |  |  |  | G |  |  |  |  |  | ▲ |  |  |  |  | ← |  |  |  |  | T► |  |  | Showing "FIN" [Finance] Menu
 |  |  |  |  |  |  |  |  |  |  |  |  |  |  |  |  |  |  |  |  |  |  | Z► |  |  | 0.00
 |  |  |  |  |  |  |  |  |  |  |  |  | R↑ ∫ |  |  |  |  | Clear
 |  |  |  |  |  |  |  |  |  |  |  |  |  |  |  |  |  |  |  |  |  |  | Y► |  |  | 50.00 |  |  |  |  |  |  |  |  |  | YÐ► |  |  |  | 53° 7' 48.3"
 |  |  |  |  |  | < |  |  |  |  |  | $ |  |  |  |  | > |  |  |  |  |  | X► |  |  | 30.00 |  |  |  |  |  |  |  |  |  | Xi ► |  |  |  | 40.00
 | α |  |  |  |  |  | ◄ |  |  |  |  |  | ▼ |  |  |  |  | ► |  |  |  |  |  |  |  |  |  |  |  |  |  |  | SL |  |  |  | 12x |  |  |  |  |  | 12÷
 |  |  |  |  |  |  |  |  |  |  |  |  |  |  |  |  |  |  |  |  |  |  |  |  |  |  |  | PRICE |  |  |  |  | SOYD |  |  |  | AMORT |  |  |  |  |  | INT
 | LBL |  |  |  |  |  | BST |  |  |  |  |  | R↓ ∂ |  |  |  |  | SST
 |  |  |  |  |  |  |  |  |  |  |  |  |  |  |  |  |  |  |  |  |  |  | ◄ |  |  |  |  | YTM |  |  |  |  | DB |  |  |  | n |  |  |  |  |  | i |  |  |  | ►
≈ |  | D.ms |  |  |  | ! |  | Sums |  |  |  | # |  | Stat |  |  | % |  | Prob |  |  | A |  | Tests |  |  | B |  | Bits |  |  | C |  | Clock |  | D |  | POL |  |  |  | E |  | EQN |  | F |  | FIN
 | ÷ |  |  |  |  |  | 7 |  |  |  |  |  | 8 |  |  |  |  | 9
 | H.ms |  |  |  |  |  | DRG |  |  |  |  |  | i Ð |  |  |  |  | SL SR
G |  |  |  |  |  | H |  | Solve |  |  |  | I |  | Ints |  |  | J |  | Fracs |  |  | K |  | Parts |  |  | L |  | Loop |  |  | M |  | Matrix |  | N |  | ÐConv |  |  |  | O |  |  |  | P
 | × |  |  |  |  |  | 4 |  |  |  |  |  | 5 |  |  |  |  | 6 |  |  |  |  | SIN |  |  |  |  | COS |  |  |  |  | TAN |  |  |  | √x |  |  |  |  |  | y^x |  |  |  | 1/x
 | DSE ISG |  |  |  |  |  | % T |  |  |  |  |  | P Cy,x |  |  |  |  | % Δ% |  |  |  |  | ASIN |  |  |  |  | ACOS |  |  |  |  | ATAN |  |  |  | x^2 x√y |  |  |  |  |  | 10^x LOG |  |  |  | e^x LN
Q |  |  |  |  |  | R |  | Bool |  |  |  | S |  | TVM |  |  | T |  | Const |  |  | U |  | Geom |  |  | V |  | P.Fcn |  |  | W |  | Flags |  | X |  | X.Fcn |  |  |  | Y |  |  |  | Z |  | RTN
 | — |  |  |  |  |  | 1 |  |  |  |  |  | 2 |  |  |  |  | 3 |  |  |  |  | +/- |  |  |  |  | EEX |  |  |  |  | π |  |  |  | x⇄y |  |  |  |  |  |  |  |  |  | XEQ
 | ST- Σ- |  |  |  |  |  | b/c .d |  |  |  |  |  | x̄ s |  |  |  |  | ŷ r |  |  |  |  | R ⇄ P |  |  |  |  | π Σ |  |  |  |  | Last x |  |  |  | x⇄ |  |  |  |  |  |  |  |  |  | GTO
? |  |  |  |  |  | ␣ |  | I / O |  |  |  | = |  | Stack |  |  |  | Pause |  |  |  |  |  |  |  |  |  |  |  |  |  |  |  |  |  |  |  |  |  |  |  |  |  |  |  |  | Off
 | + |  |  |  |  |  | 0 |  |  |  |  |  | . |  |  |  |  | R / S |  |  |  |  | ENTER |  |  |  |  |  |  |  |  |  | STO |  |  |  | RCL |  |  |  |  |  | User |  |  |  | Exit
 | ST+ Σ+ |  |  |  |  |  |  |  |  |  |  |  |  |  |  |  |  | Prgm |  |  |  |  | Catalog |  |  |  |  |  |  |  |  |  | Assig |  |  |  | View |  |  |  |  |  | Modes |  |  |  | On
RAD |  |  |  |  |  |  |  | ^ |  | UP
MTH |  |  |  | PRG |  |  |  | ▲ |  |  |  | ←
POLAR |  |  |  | CHARS |  |  |  | STACK |  |  |  | DROP
MENU |  |  |  | < |  | DEL |  |  |  | HOME |  | > |  | CLEAR
NXT |  |  |  | ◄ |  |  |  | ▼ |  |  |  | ►
PREV |  |  |  | PICTURE |  |  |  | VIEW |  |  |  | SWAP
 |  | # |  | ! |  |  |  | $ |  |  |  | % |  |  |  | A |  |  | B |  |  | C |  |  |  | D |  |  | E |  |  | F
÷ |  |  |  | 7 |  |  |  | 8 |  |  |  | 9
( ) |  |  |  | SOLVE |  |  |  | PLOT |  |  |  | SYMBOLIC
 |  | _ |  | G |  | EVAL |  | H |  | UNDO |  | I |  | NUM |  | J | EDIT |  | K |  | DEF | L |  | ' |  | M |  |  | N |  | DEF | O |  | y^1/x
× |  |  |  | 4 |  |  |  | 5 |  |  |  | 6 |  |  |  | +/- |  |  | STO |  |  | PRG |  |  |  | CST |  |  | STO |  |  | SQRT
[ ] |  |  |  | TIME |  |  |  | STAT |  |  |  | UNITS |  |  |  | CMD |  |  | RCL |  |  | CHARS |  |  |  | MODES |  |  | RCL |  |  | x^2
 |  | " " |  | P |  |  |  | Q |  |  |  | R |  |  |  | S | PURG |  | T |  | LOG | U |  | LN |  | V | ∂ |  | W |  | ∫ | X |  | Σ
— |  |  |  | 1 |  |  |  | 2 |  |  |  | 3 |  |  |  | EEX |  |  | y^x |  |  | 1/X |  |  |  | SIN |  |  | COS |  |  | TAN
<< >> |  |  |  | I/O |  |  |  | LIBRARY |  |  |  | EQN LIB |  |  |  | ARG |  |  | 10^x |  |  | e^x |  |  |  | ASIN |  |  | ACOS |  |  | ATAN
 |  | : : |  |  |  | → |  | Y |  | ←┘ |  | Z |  | Ð |  |  |  |  | MATRIX |  |  |  |  | USER |  |  |  |  |  |  |  |  |  | CONT
+ |  |  |  | 0 |  |  |  | . |  |  |  | SPC |  |  |  | ENTER |  |  |  |  |  | α |  |  |  | F |  |  | G |  |  | ON
{ } |  |  |  | = |  |  |  | , |  |  |  | π |  |  |  | EQUATION |  |  |  |  |  | ENTRY |  |  |  |  |  |  |  |  |  | OFF

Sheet: Menus
Menu |  | Straight | F | H | Menu |  | Straight | F | H | Menu |  | Straight | F | H | Menu |  | Straight |  | F
SOLVE | A |  |  |  | Plot | A | Zoom |  |  | Symb | A |  |  |  | Test | A | == | Equal, Z = 1 | != | Not Equal, Z = 0
 | B |  |  |  |  | B | (x,y) |  |  |  | B |  |  |  |  | B | CS | Carry Set, C = 1 | CC | Carry Clear, C = 0
 | C |  |  |  |  | C | Trace |  |  |  | C |  |  |  |  | C | >= | U / S Higher or Same, C = 1 | < | U / S Lower, C = 0
 | D |  |  |  |  | D | FCN |  |  |  | D |  |  |  |  | D | < 0 | Minus, N = 1 | > 0 | Plus, N = 0
 | E |  |  |  |  | E | Edit |  |  |  | E |  |  |  |  | E | VS | Overflow, V = 1 | VC | No Overflow, V = 0
 | F |  |  |  |  | F | Cancl |  |  |  | F |  |  |  |  | F | > | U / S Higher, C = 1 , Z = 0 | <= | U / S Lower or same, C = 0, Z = 1
Time | A | H.ms | H.d |  | Stat | A |  |  |  | Units | A | Length | Heat
 | B | H.ms+ | H.ms- |  |  | B | x hat |  |  |  | B | Mass | Time
 | C | 12h | 24h |  |  | C | y |  |  |  | C | Volume | Electr
 | D | Ticks |  |  |  | D | r |  |  |  | D | Area | Speed
 | E |  |  |  |  | E | s |  |  |  | E | Freq
 | F |  |  |  |  | F |  |  |  |  | F | Metric | Imperial
Prob | A | Pois |  |  | Lib | A |  |  |  | Eqn Lib | A
 | B | Binom |  |  |  | B |  |  |  |  | B
 | C |  |  |  |  | C |  |  |  |  | C
 | D |  |  |  |  | D |  |  |  |  | D
 | E |  |  |  |  | E |  |  |  |  | E
 | F | P y,x | C y, x |  |  | F |  |  |  |  | F
Mode | A | Int | Real | Double | Menu | A |  |  |  | Flags | A | SF | FS? | VS
 | B | Complex |  | BCD |  | B |  |  |  |  | B | CF | FC? | VC
 | C | DRG► | ◄DRG |  |  | C |  |  |  |  | C | FS?C | FS?S | FS?T
 | D | B2 | B8 | Bn |  | D |  |  |  |  | D | FC?C | FC?S | FC?T
 | E | B10 | B16 |  |  | E |  |  |  |  | E | ISG | ISE
 | F | 1's Comp | 2's Comp |  |  | F |  |  |  |  | F | DSL | DSE | DSZ
Const | A |  |  |  | Logic | A | And | Nand | Xor | TRIG | A | sinh | asinh | D-R
 | B |  |  |  |  | B | Or | Nor | Xnor |  | B | cosh | acosh | D-G
 | C |  |  |  |  | C | Not | TEST | CS |  | C | tanh | atanh | R-D
 | D |  |  |  |  | D | == | != | CC |  | D | sin | asin | R-G
 | E |  |  |  |  | E | <= | < | < 0 |  | E | cos | acos | G-D
 | F |  |  |  |  | F | >= | > | > 0 |  | F | tan | atan | G-R
X.Fcn | A |  |  |  | I/O | A | Save | Load |  | Prgm | A
 | B |  |  |  |  | B | Print |  |  |  | B
 | C |  |  |  |  | C |  |  |  |  | C
 | D |  |  |  |  | D |  |  |  |  | D
 | E |  |  |  |  | E |  |  |  |  | E
 | F |  |  |  |  | F |  |  |  |  | F
Matrix | A | Edit
 | B | Vec
 | C | <-Wid
 | D | Wid->
 | E | Go->
 | F | Go▼

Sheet: Thoughts
A |  | Solve |  |  | B |  | Plot |  | C | Symb | D |  | Time | E | Stat | F | Units | G |  | H |  |  |  | ≈ | Stk |  | CLΣ
 |  |  |  |  |  |  |  |  |  |  |  |  |  |  |  |  |  | 1/x |  | √x |  |  |  | ▲ |  |  | CLR
 |  |  |  |  |  |  |  |  |  |  |  |  |  |  |  |  |  | y^x |  | x^2 |x| |  |  |  | Drop |  |  | Del
I |  | Prob |  |  | J |  | Lib |  | K | Eq Lb | L |  | Fin | M | I / O | N | Flags | O |  | < | << |  |  | # |  |  | > | >>
× |  |  |  |  | 7 |  |  |  | 8 |  | 9 |  |  | +/- |  | LOG |  | Ln |  | ◄ |  |  |  | ▼ |  |  | ►
i Ð |  |  |  |  | RC PO |  |  |  | H.ms |  | Δ% |  |  | X.Fcn |  | 10^x |  | e^ 2^x |  | [ ] |  |  |  | R↓ ↑ |  |  | Swap
P |  | Logic |  |  | Q |  | Const |  | R |  | S |  |  | T |  | U |  | V |  | " |  |  |  | ; |  |  | @
÷ |  |  |  |  | 4 |  |  |  | 5 |  | 6 |  |  | EXP |  | x⇄y |  | Hyp |  | SIN |  |  |  | COS |  |  | TAN
Fix :: |  |  |  |  | b/c .d |  |  |  | P Cy,x |  | DRG◄ |  |  | Lin R |  | " " 2d |  | Eqn π |  | asin ∂ |  |  |  | acos ∫ |  |  | atan Σ
W |  |  |  |  | X |  |  |  | Y |  | Z |  |  |  |  | ! |  | & |  | % |  |  |  | ^ |  |  | $ | Cat
+ |  |  |  |  | 1 |  |  |  | 2 |  | 3 |  |  | E N T E R |  | STO |  | RCL |  | Mode |  |  |  | Menu |  |  | XEQ
Sci Σ+ |  |  |  |  |  |  |  |  |  |  |  |  |  |  |  | x! !( ) |  | Eval && |  | Mod || |  |  |  | xor |  |  | GTO
( |  |  |  |  | ) |  |  |  | Space |  |  |  | RTN |  |  | : |  |  | Prgm |  |  | H |  |  |  |  |  | Off
- |  |  |  |  | 0 |  |  |  | . |  | R / S |  |  |  |  | SST |  | α |  | G |  |  |  | F |  |  | ON
Eng Σ- |  |  |  |  |  |  |  |  | , = |  | LBL |  |  | Matrix |  | BST |  | User |  |  |  |  |  |  |  |  | Off
 | Mode: |  |  | 12h |  | 12 Hour Clock |  |  |  |  |  | 10 x 5 = 50 keys (ENTER = 2 spaces) -> 49 Keys |  |  |  |  |  |  |  | ARM Flags: |  | Z | Zero |  |  | C | Carry
 |  |  |  | 1C |  | Integer, 1's Complement |  |  |  |  |  |  |  |  |  |  |  |  |  |  |  | N | Negative |  |  | V | Overflow
 |  |  |  | 24h |  | 24 Hour Clock
 |  |  |  | 2C |  | Integer, 2's Complement
 |  |  |  | Base n |  | Integer, Base (2 to 16)
 |  |  |  | BestF |  | "Best Fit" curve model
 |  |  |  | CAS |  | Computer Algebra System (Symbolic math)
 |  |  |  | CPX |  | Complex math
 |  |  |  | DBL |  | "Double" Precision
 |  |  |  | FAST |  | Faster CPU, uses more battery power (Default)
 |  |  |  | SLOW |  | Slower CPU, saves battery
 |  |  | ANGLE: |  |  |  |  | Symbol font, code 208

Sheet: 1
RAD |  |  |  | ^ | UP
MTH |  | PRG |  | ▲ |  | ←
POLAR |  | CHARS |  | STACK |  | DROP
MENU |  | < | DEL |  | HOME | > | CLEAR
NXT |  | ◄ |  | ▼ |  | ►
PREV |  | PICTURE |  | VIEW |  | SWAP
 | # | ! |  | $ |  | % |  | A |  | B |  | C |  | D |  | E |  | F
÷ |  | 7 |  | 8 |  | 9
( ) |  | SOLVE |  | PLOT |  | SYMBOLIC
 | _ | G | EVAL | H | UNDO | I | NUM | J | EDIT | K | DEF | L | ' | M |  | N | DEF | O | y^1/x
× |  | 4 |  | 5 |  | 6 |  | +/- |  | STO |  | PRG |  | CST |  | STO |  | SQRT
[ ] |  | TIME |  | STAT |  | UNITS |  | CMD |  | RCL |  | CHARS |  | MODES |  | RCL |  | x^2
 | " " | P |  | Q |  | R |  | S | PURG | T | LOG | U | LN | V | ∂ | W | ∫ | X | Σ
— |  | 1 |  | 2 |  | 3 |  | EEX |  | y^x |  | 1/X |  | SIN |  | COS |  | TAN
<< >> |  | I/O |  | LIBRARY |  | EQN LIB |  | ARG |  | 10^x |  | e^x |  | ASIN |  | ACOS |  | ATAN
 | : : |  | → | Y | ←┘ | Z | Ð |  |  | MATRIX |  |  | USER |  |  |  |  |  | CONT
+ |  | 0 |  | . |  | SPC |  | ENTER |  |  |  | α |  | F |  | G |  | ON
{ } |  | = |  | , |  | π |  | EQUATION |  |  |  | ENTRY |  |  |  |  |  | OFF
 |  |  |  |  |  |  |  |  |  |  |  |  |  |  |  |  |  |  |  |  | Screen: |  | Key: |  | Display |  | Char width |  | Char/key
 |  |  |  |  |  |  |  |  |  |  |  |  |  |  |  |  |  |  |  | Screen | Width | Height | Width |  | Width |  | 5 | 6 | 7 | 8
 |  |  |  |  |  |  |  |  |  |  |  |  |  |  |  |  |  |  |  | Ipad | 1024 | 768 | 100 |  | 600 |  | 20 | 16.7 | 14.3 | 12.5
 |  |  |  |  |  |  |  |  |  |  |  |  |  |  |  |  |  |  |  | Nexus 7 | 1920 | 1200 | 190 |  | 1140 |  | 38 | 31.7 | 27.1 | 23.75
 |  |  |  |  |  |  |  |  |  |  |  |  |  |  |  |  |  |  |  |  |  |  |  |  |  |  | Display Height
 |  |  |  |  |  |  |  |  |  |  |  |  |  |  |  |  |  |  |  | Screen | Width | Height |  | Height |  |  | Key | Rows
 |  |  |  |  |  |  |  |  |  |  |  |  |  |  |  |  |  |  |  |  |  |  |  |  |  |  | 3 | 4 | 5 | 6 | 7
 |  |  |  |  |  |  |  |  |  |  |  |  |  |  |  |  |  |  |  | Ipad | 1024 | 768 | 24 | 72 | 600 | x | 552 | 480 | 408 | 336 | 264
 |  |  |  |  |  |  |  |  |  |  |  |  |  |  |  |  |  |  |  | Nexus 7 | 1920 | 1200 | 48 | 144 | 1140 | x | 768 | 624 | 480 | 336 | 192
 |  |  |  |  |  |  |  |  |  |  |  |  |  |  |  |  |  |  |  |  |  |  |  |  |  |  | Display Height
 |  |  |  |  |  |  |  |  |  |  |  |  |  |  |  |  |  |  |  | Screen | Width | Height |  | Height |  |  | Key | Rows
 |  |  |  |  |  |  |  |  |  |  |  |  |  |  |  |  |  |  |  |  |  |  |  |  |  |  | 3 | 4 | 5 | 6 | 7
 |  |  |  |  |  |  |  |  |  |  |  |  |  |  |  |  |  |  |  | Ipad | 1024 | 768 | 27 | 81 | 600 | x | 525 | 444 | 363 | 282 | 201
 |  |  |  |  |  |  |  |  |  |  |  |  |  |  |  |  |  |  |  | Nexus 7 | 1920 | 1200 | 50 | 150 | 1140 | x | 750 | 600 | 450 | 300 | 150
 |  |  |  |  |  |  |  |  |  |  |  |  |  |  |  |  |  |  |  |  |  |  |  |  |  |  | Display Height
 |  |  |  |  |  |  |  |  |  |  |  |  |  |  |  |  |  |  |  | Screen | Width | Height |  | Height |  |  | Key | Rows
 |  |  |  |  |  |  |  |  |  |  |  |  |  |  |  |  |  |  |  |  |  |  |  |  |  |  | 3 | 4 | 5 | 6 | 7
 |  |  |  |  |  |  |  |  |  |  |  |  |  |  |  |  |  |  |  | Ipad | 1024 | 768 | 32 | 96 | 600 | x | 480 | 384 | 288 | 192 | 96
 |  |  |  |  |  |  |  |  |  |  |  |  |  |  |  |  |  |  |  | Nexus 7 | 1920 | 1200 | 55 | 165 | 1140 | x | 705 | 540 | 375 | 210 | 45
 |  |  |  |  |  |  |  |  |  |  |  |  |  |  |  |  |  |  |  |  |  |  |  |  |  |  | Display Height
 |  |  |  |  |  |  |  |  |  |  |  |  |  |  |  |  |  |  |  | Screen | Width | Height |  | Height |  |  | Key | Rows
 |  |  |  |  |  |  |  |  |  |  |  |  |  |  |  |  |  |  |  |  |  |  |  |  |  |  | 3 | 4 | 5 | 6 | 7
 |  |  |  |  |  |  |  |  |  |  |  |  |  |  |  |  |  |  |  | Ipad | 1024 | 768 | 36 | 108 | 600 | x | 444 | 336 | 228 | 120 | 12
 |  |  |  |  |  |  |  |  |  |  |  |  |  |  |  |  |  |  |  | Nexus 7 | 1920 | 1200 | 57 | 171 | 1140 | x | 687 | 516 | 345 | 174 | 3
 |  |  |  |  |  |  |  |  |  |  |  |  |  |  |  |  |  |  |  |  |  |  |  |  | 50 |  |  | 11.64285714 |  | 750
 |  |  |  |  |  |  |  |  |  |  |  |  |  |  |  |  |  |  |  |  |  |  |  |  | 22.8 |  | 489 |  |  | 624
 |  |  |  |  |  |  |  |  |  |  |  |  |  |  |  |  |  |  |  |  |  |  |  |  |  |  |  |  |  | 8.914285714

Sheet: Switch
Part # | # Pins | PCB: Area | PCB: W | PCB: H | Height | Cost [50] |  | Store | Manuf | Travel | Comments
SKRK | 2 |  |  |  |  |  |  |  | ALPS
SKSFABE010 | 4 | 7.2 | 3.2 | 2.25 | 0.65 | $0.726 | $36.30 | Mouser | ALPS | 0.1
EVQ-PQHB55 | 4 | 23.28 | 4.85 | 4.8 | 0.55 | $0.391 | $19.53 | Digi-Key | Panasonic
TL-3313 A-F100-Q-G | 4 | 25.6 | 6.4 | 4 | 1.5 |  |  |  | E-Switch
TL-3301 N-F160-Q-J | 4 | 41.3 | 7 | 5.9 | 4.3 | $0.522 | $26.11 | Digi-Key | E-Switch |  | J-Lead: folds under body
B3FS | 4 | 56.64 | 9.6 | 5.9 | 3.1 |  |  |  | Omron
EVP-AA 002K | 4 | 11.25 | 4.5 | 2.5 |  | $0.954 | $47.68 | Digi-Key | Panasonic
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

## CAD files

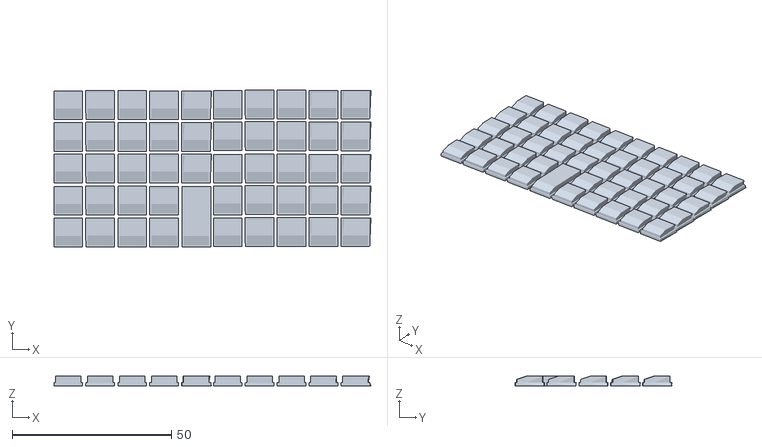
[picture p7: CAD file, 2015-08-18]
docs/PDF/Keypad/Keypad_1.stl
99.4 x 49.2 x 3.00

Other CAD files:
docs/PDF/Keypad/Keypad_1.dxf
docs/PDF/Keypad/Keypad_1.skp

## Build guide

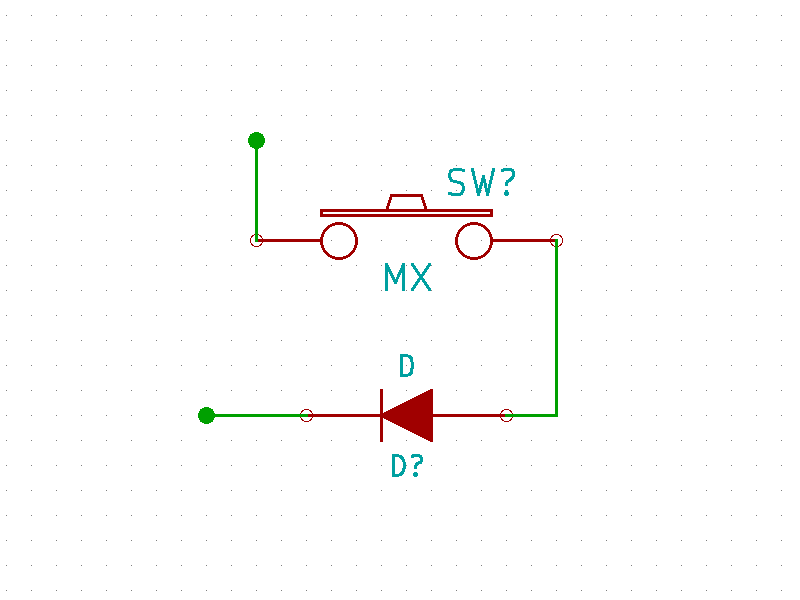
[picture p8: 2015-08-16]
docs/PDF/Keys/KiCAD_tutorial-01_Single_switch.png

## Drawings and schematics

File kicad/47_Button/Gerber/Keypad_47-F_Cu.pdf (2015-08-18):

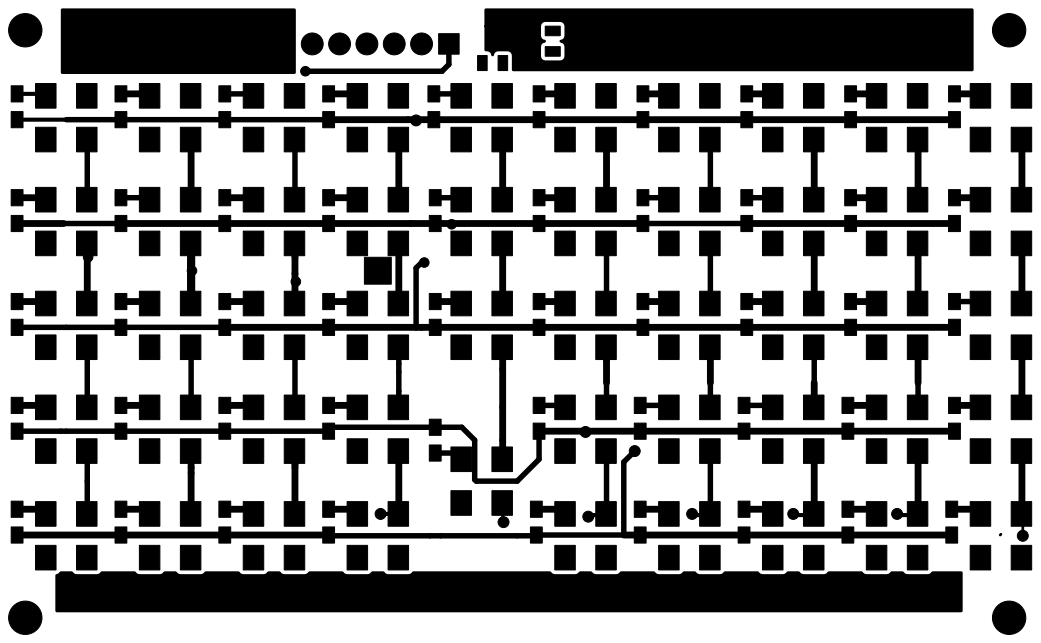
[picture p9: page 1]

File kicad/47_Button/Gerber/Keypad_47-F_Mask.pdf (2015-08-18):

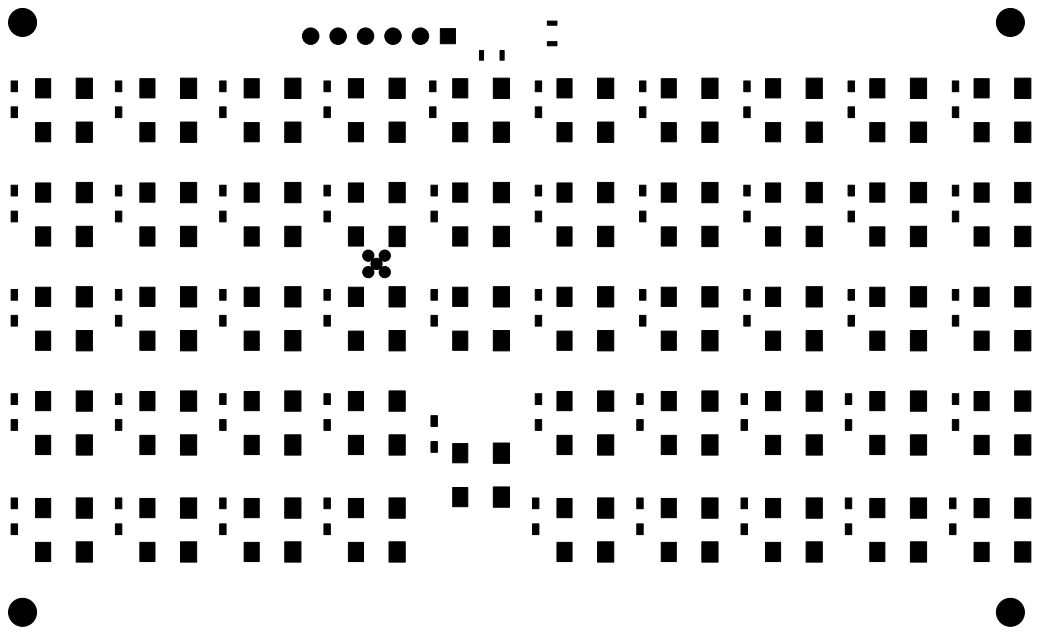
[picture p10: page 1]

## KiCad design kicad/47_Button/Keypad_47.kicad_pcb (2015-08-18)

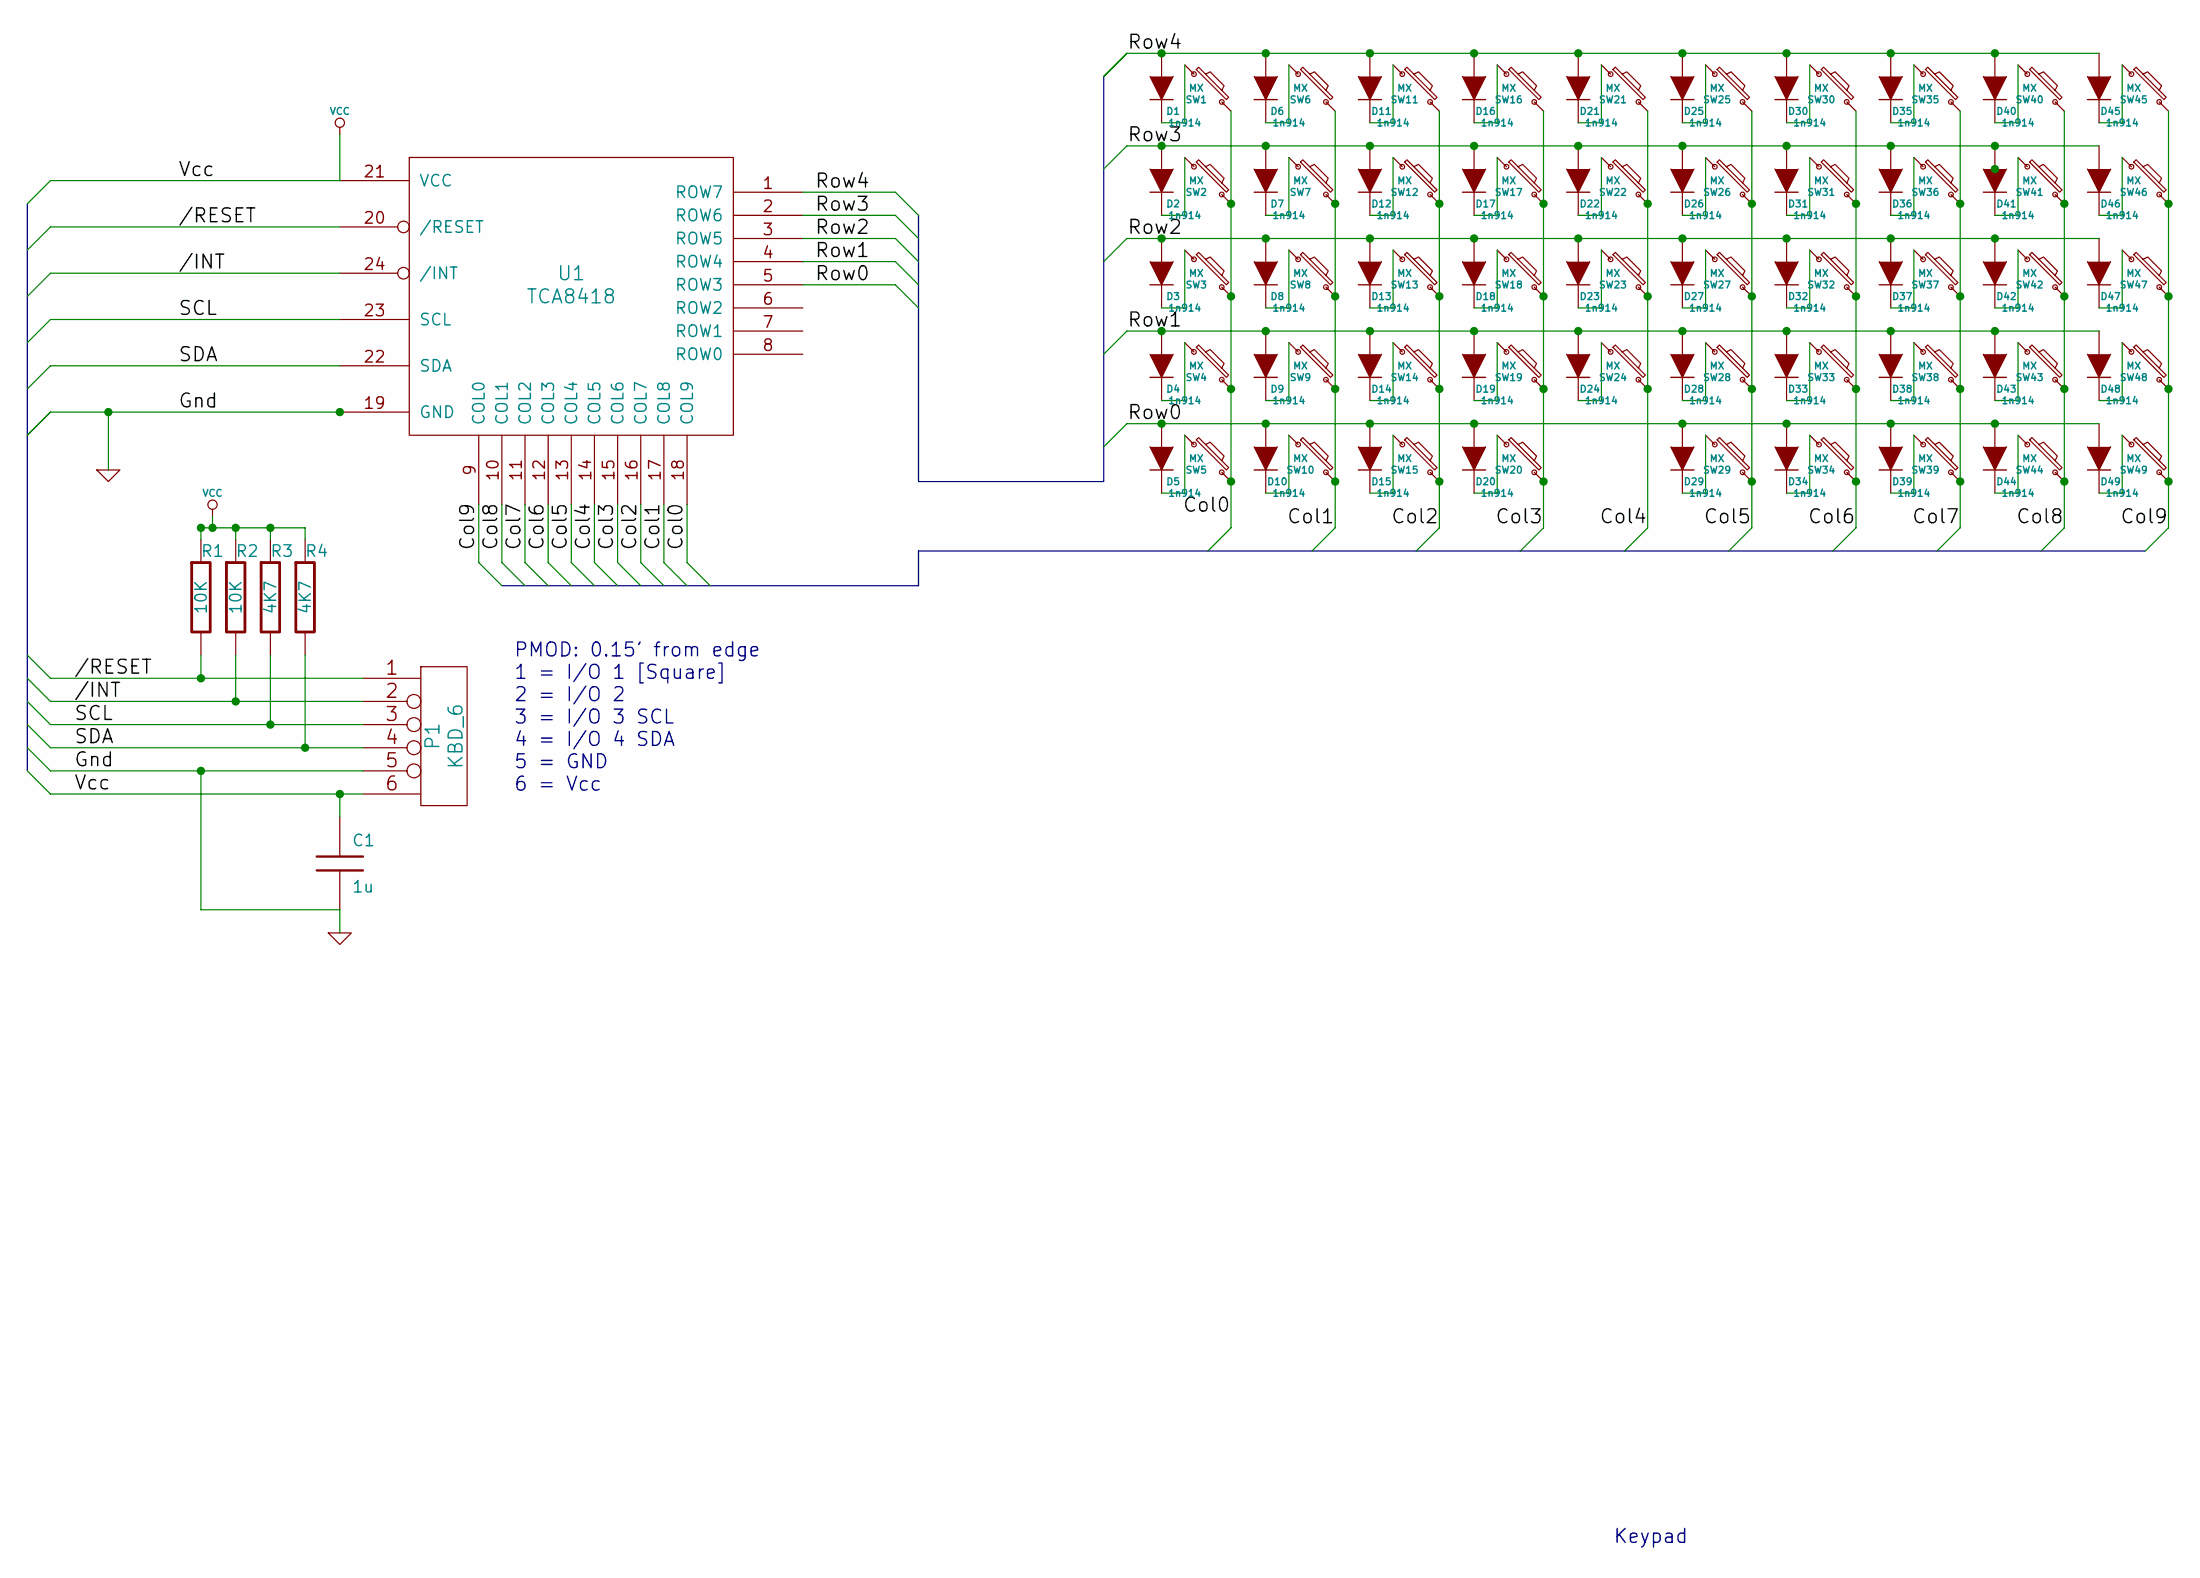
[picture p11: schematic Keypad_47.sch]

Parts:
C1: 1u
D1, D2, D3, D4, D5, D6, D7, D8, D9, D10, D11, D12, D13, D14, D15, D16, D17, D18, D19, D20, D21, D22, D23, D24, D25, D26, D27, D28, D29, D30, D31, D32, D33, D34, D35, D36, D37, D38, D39, D40, D41, D42, D43, D44, D45, D46, D47, D48, D49: 1n914
P1: KBD_6
R1, R2: 10K
R3, R4: 4K7
SW1, SW2, SW3, SW4, SW5, SW6, SW7, SW8, SW9, SW10, SW11, SW12, SW13, SW14, SW15, SW16, SW17, SW18, SW19, SW20, SW21, SW22, SW23, SW24, SW25, SW26, SW27, SW28, SW29, SW30, SW31, SW32, SW33, SW34, SW35, SW36, SW37, SW38, SW39, SW40, SW41, SW42, SW43, SW44, SW45, SW46, SW47, SW48, SW49: MX
U1: TCA8418

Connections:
//INT: P1.2, R2.2, U1.24 (/INT)
//RESET: P1.1, R1.2, U1.20 (/RESET)
/Col0: SW1.2, SW2.2, SW3.2, SW4.2, SW5.2, U1.18 (COL9)
/Col1: SW6.2, SW7.2, SW8.2, SW9.2, SW10.2, U1.17 (COL8)
/Col2: SW11.2, SW12.2, SW13.2, SW14.2, SW15.2, U1.16 (COL7)
/Col3: SW16.2, SW17.2, SW18.2, SW19.2, SW20.2, U1.15 (COL6)
/Col4: SW21.2, SW22.2, SW23.2, SW24.2, U1.14 (COL5)
/Col5: SW25.2, SW26.2, SW27.2, SW28.2, SW29.2, U1.13 (COL4)
/Col6: SW30.2, SW31.2, SW32.2, SW33.2, SW34.2, U1.12 (COL3)
/Col7: SW35.2, SW36.2, SW37.2, SW38.2, SW39.2, U1.11 (COL2)
/Col8: SW40.2, SW41.2, SW42.2, SW43.2, SW44.2, U1.10 (COL1)
/Col9: SW45.2, SW46.2, SW47.2, SW48.2, SW49.2, U1.9 (COL0)
/Row0: D5.1 (A), D10.1 (A), D15.1 (A), D20.1 (A), D29.1 (A), D34.1 (A), D39.1 (A), D44.1 (A), D49.1 (A), U1.5 (ROW3)
/Row1: D4.1 (A), D9.1 (A), D14.1 (A), D19.1 (A), D24.1 (A), D28.1 (A), D33.1 (A), D38.1 (A), D43.1 (A), D48.1 (A), U1.4 (ROW4)
/Row2: D3.1 (A), D8.1 (A), D13.1 (A), D18.1 (A), D23.1 (A), D27.1 (A), D32.1 (A), D37.1 (A), D42.1 (A), D47.1 (A), U1.3 (ROW5)
/Row3: D2.1 (A), D7.1 (A), D12.1 (A), D17.1 (A), D22.1 (A), D26.1 (A), D31.1 (A), D36.1 (A), D41.1 (A), D46.1 (A), U1.2 (ROW6)
/Row4: D1.1 (A), D6.1 (A), D11.1 (A), D16.1 (A), D21.1 (A), D25.1 (A), D30.1 (A), D35.1 (A), D40.1 (A), D45.1 (A), U1.1 (ROW7)
/SCL: P1.3, R3.2, U1.23 (SCL)
/SDA: P1.4, R4.2, U1.22 (SDA)
GND: C1.2, P1.5, U1.19 (GND)
unnamed: D1.2 (K), SW1.1
unnamed: D2.2 (K), SW2.1
unnamed: D3.2 (K), SW3.1
unnamed: D4.2 (K), SW4.1
unnamed: D5.2 (K), SW5.1
unnamed: D6.2 (K), SW6.1
unnamed: D7.2 (K), SW7.1
unnamed: D8.2 (K), SW8.1
unnamed: D9.2 (K), SW9.1
unnamed: D10.2 (K), SW10.1
unnamed: D11.2 (K), SW11.1
unnamed: D12.2 (K), SW12.1
unnamed: D13.2 (K), SW13.1
unnamed: D14.2 (K), SW14.1
unnamed: D15.2 (K), SW15.1
unnamed: D16.2 (K), SW16.1
unnamed: D17.2 (K), SW17.1
unnamed: D18.2 (K), SW18.1
unnamed: D19.2 (K), SW19.1
unnamed: D20.2 (K), SW20.1
unnamed: D21.2 (K), SW21.1
unnamed: D22.2 (K), SW22.1
unnamed: D23.2 (K), SW23.1
unnamed: D24.2 (K), SW24.1
unnamed: D25.2 (K), SW25.1
unnamed: D26.2 (K), SW26.1
unnamed: D27.2 (K), SW27.1
unnamed: D28.2 (K), SW28.1
unnamed: D29.2 (K), SW29.1
unnamed: D30.2 (K), SW30.1
unnamed: D31.2 (K), SW31.1
unnamed: D32.2 (K), SW32.1
unnamed: D33.2 (K), SW33.1
unnamed: D34.2 (K), SW34.1
unnamed: D35.2 (K), SW35.1
unnamed: D36.2 (K), SW36.1
unnamed: D37.2 (K), SW37.1
unnamed: D38.2 (K), SW38.1
unnamed: D39.2 (K), SW39.1
unnamed: D40.2 (K), SW40.1
unnamed: D41.2 (K), SW41.1
unnamed: D42.2 (K), SW42.1
unnamed: D43.2 (K), SW43.1
unnamed: D44.2 (K), SW44.1
unnamed: D45.2 (K), SW45.1
unnamed: D46.2 (K), SW46.1
unnamed: D47.2 (K), SW47.1
unnamed: D48.2 (K), SW48.1
unnamed: D49.2 (K), SW49.1
VCC: C1.1, P1.6, R1.1, R2.1, R3.1, R4.1, U1.21 (VCC)

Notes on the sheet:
PMOD: 0.15' from edge 1 = I/O 1 [Square] 2 = I/O 2 3 = I/O 3 SCL 4 = I/O 4 SDA 5 = GND 6 = Vcc
Keypad

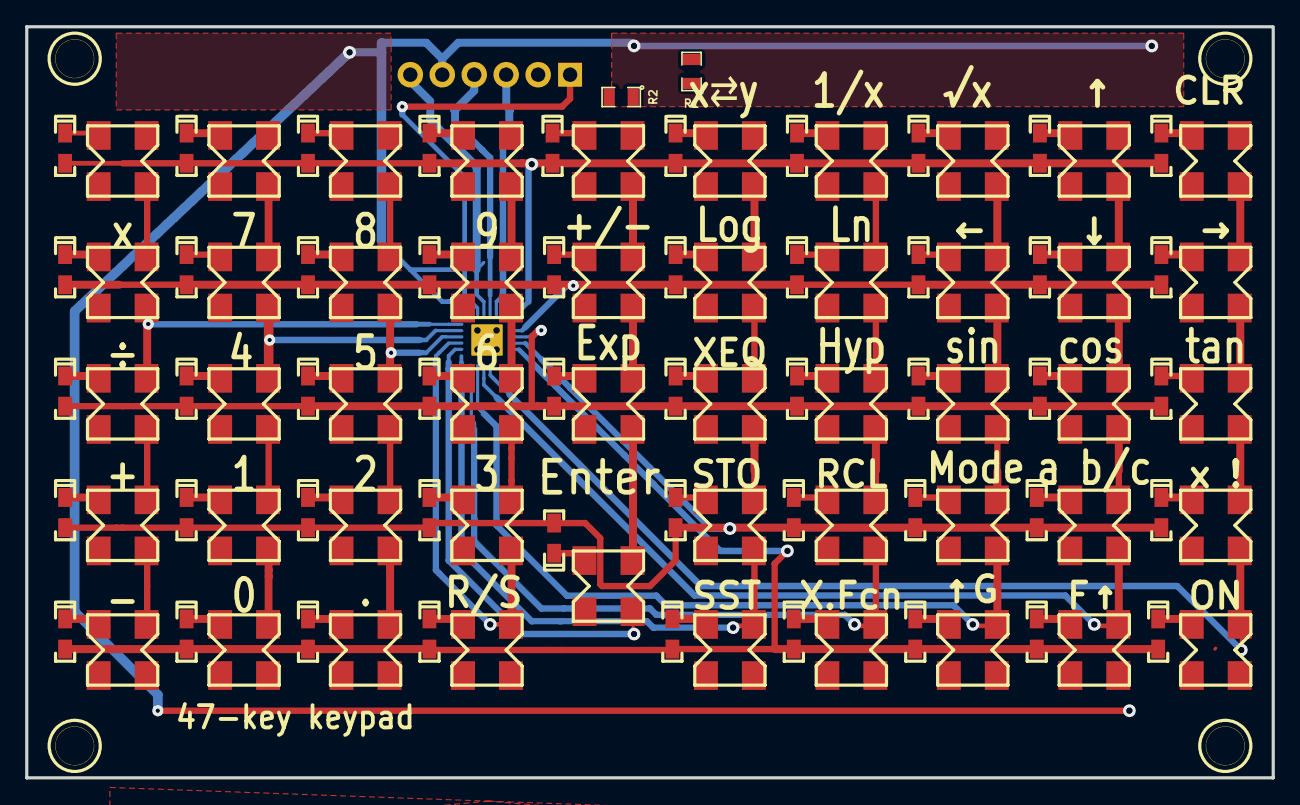
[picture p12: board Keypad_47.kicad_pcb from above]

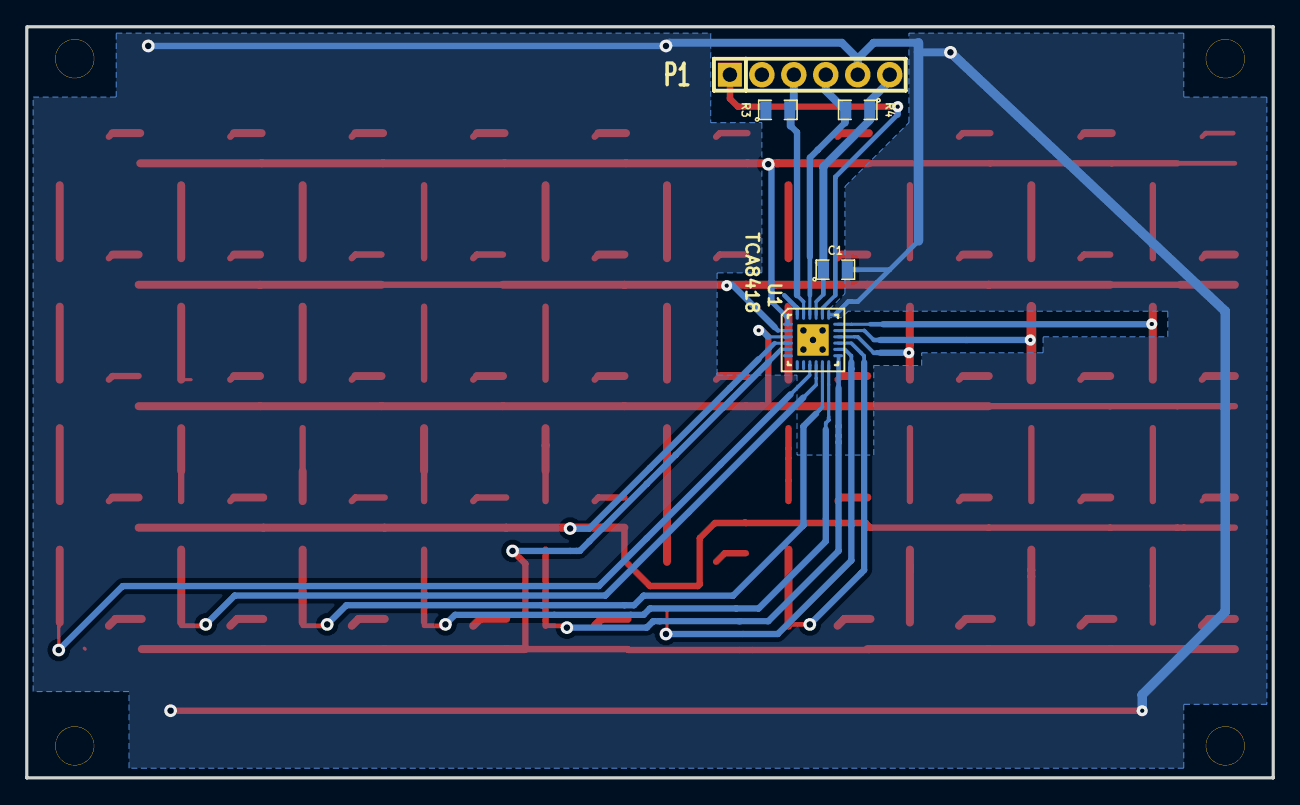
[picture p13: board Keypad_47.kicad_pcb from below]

Board: 2 copper layers, 99.1 x 59.7 mm, 109 parts (5 on the bottom side), 70 nets.

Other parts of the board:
1PIN, 1PIN#2, 1PIN#3, 1PIN#4: P***; 1_Pin

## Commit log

2013-10-04 Version 0.1 initial files
    [$savepcb.brd, Keypad.kicad_pcb, Keypad.sch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]
2013-10-25 Update for 10cm x 5cm PCB
    [$savepcb.brd, Keypad.sch]
2013-10-25 Adding extra files
    [Keypad.brd]
2014-01-30 updating files
    [$savepcb.brd, Keypad_49.brd, Keypad_49.sch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]
2015-08-16 Update 2c
    2 layouts, and a virtual keypad for use with Android Nexus 7
    [$savepcb.brd, 12x6_Layout.xls, Calc_Design.xls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]
2015-08-18 Tidy up structure
    [12x6_Layout.xls, Calc_Design.xls, Keypad_1.dxf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]
2015-08-18 Tidy up
    [2014_49-Key_Layout.xls, 2015_47-Key_Layout.xls, Ideas_12x6_Layout.xls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]
